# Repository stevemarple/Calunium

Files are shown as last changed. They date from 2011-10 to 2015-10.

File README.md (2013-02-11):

# Calunium

Calunium is an Arduino clone using the ATmega164A, ATmega164PA
ATmega324A, ATmega324PA, ATmega644A, ATmega644PA, ATmega1284 or
ATmega1284P microcontroller. The layout is designed for easy assembly
and maximum compatibility with the Arduino Uno, with additional
functionality being compatible with the Arduino Mega(2560).

## License

Unless indicated otherwise hardware is released under the Creative
Commons Attribution-ShareAlike 3.0 Unported (CC BY-SA 3.0)
http://creativecommons.org/licenses/by-sa/3.0/

Unless indicated otherwise software is released under the GNU Lesser
General Public License, version 2.1.
http://www.gnu.org/licenses/lgpl-2.1.html

## Versions

A brief description of the versions is given below. In each case
peripherals can be omitted form the build if not need.

### Stripboard version

The analogue pin mapping differs slightly for the stripboard
version. For more information see
http://blog.stevemarple.co.uk/2011/08/introducing-calunium-arduino-clone.html

### PCB version 1

Includes a real-time clock and LM61 temperature sensor. Standard
Arduino headers and JTAG, FTDI and auxillary power connectors. USB
connector for power and V-USB interface (not confirmed to work). Can
be operated at 3.3V or 5V depending upon build configuration. Not
jumper selectable. For more information see
http://blog.stevemarple.co.uk/2011/11/calunium-pcb-version.html.

### PCB version 2

Includes real-time clock, micro-SD socket, RFM12B radio module, and
LM61 temperature sensor. Arduino 1.0 headers with IOREF and dedicated
I2C pins. JTAG, FTDI and auxillary power connectors.  USB connector
for power only. Jumper-selectable 3.3V or 5V operation. For more
information see
http://blog.stevemarple.co.uk/2012/12/calunium-version-2.html

### PCB version 2.1

Includes MCP2200 USB-UART converter, real-time clock, micro-SD socket,
RFM12B radio module, and LM61 temperature sensor. Arduino 1.0 headers
with IOREF and dedicated I2C pins. JTAG and auxillary power
connectors. If the MCP2200 is fitted then the FTDI connector cannot be
fitted, but the USB socket is enabled for data. If the MCP2200 is not
fitted the FTDI connector can be, but the USB socket is for power
only. Jumper-selectable 3.3V or 5V operation. For more information see

The headers include
IOREF and dedicated I2C pins. For more information see
http://blog.stevemarple.co.uk/2013/02/calunium-version-21.html and
http://blog.stevemarple.co.uk/2012/12/calunium-version-2.html.

## Bootloader

Xboot and OptiBoot bootloaders are included. To avoid too many items
in boards menu the optiboot versions are commented out.

The xboot source files can be found at
https://github.com/stevemarple/xboot.

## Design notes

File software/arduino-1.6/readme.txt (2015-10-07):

Software to support Calunium in the Arduino IDE. 
Requires Arduino version >= 1.5.

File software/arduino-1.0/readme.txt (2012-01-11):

Software to support Calunium in the Arduino IDE. 
Requires Arduino 1.0.

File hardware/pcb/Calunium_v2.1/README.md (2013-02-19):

# Calunium v2.1 PCB design

Calunium design files for Eagle 6.2.0.

Tested design. Only known error is label for JP9. Order is incorrect and
should read "USB/FTDI" to match jumper position.

## Licence
Creative Commons Attribution-ShareAlike 3.0 Unported (CC BY-SA 3.0)
http://creativecommons.org/licenses/by-sa/3.0/

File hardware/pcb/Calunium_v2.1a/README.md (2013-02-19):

# Calunium v2.1a PCB design

Calunium design files for Eagle 6.2.0.

Identical to Calunium v2.1 but corrects for silkscreen error on JP9.

## Licence
Creative Commons Attribution-ShareAlike 3.0 Unported (CC BY-SA 3.0)
http://creativecommons.org/licenses/by-sa/3.0/

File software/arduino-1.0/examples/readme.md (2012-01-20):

# Software examples

These software examples should work unchanged on a Calunium, for other
ATmega*4 devices you may need to use a different pin number; make sure
you use the same MCU pin as here. Arduino users will probably need to
make some changes; see the comments in the code.

## RTCInterrupts

An example sketch which uses Calunium's on-board real-time clock to
create interrupts which are processed by the INT2 interrupt service
routine.

## RTCPinChangeInterrupts

An example sketch which uses Calunium's on-board real-time clock to
create pin-change interrupts.

## RTCTimerCounter

An example sketch which uses Calunium's on-board real-time clock to
drive the counter stage of timer/counter2. When the counter reaches a
predetermined value (but not overflow) an interrupt is generated.

## RTCSquareWaveOff

An example sketch to turn off the square wave output of the real-time
clock.

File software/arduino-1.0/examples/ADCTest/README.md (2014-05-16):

# ADCTest.ino
 
Example sketch to demonstrate using the analogue to digital
converters, and how to change the analogue reference.

The output of all ADCs are continously printed to the serial port,
with a 1s delay between each set of readings. The analogue
reference can be changed during operation by sending one of the
following characters:
    1: Set analog reference to INTERNAL1V1");
    2: Set analog reference to INTERNAL2V56");
    d: Set analog reference to DEFAULT (Vcc)");
    e: Set analog reference to EXTERNAL");
Sending h (or ?) prints help information about the characters which
are accepted.

Author: Steve Marple
License: GNU General Public License version 2

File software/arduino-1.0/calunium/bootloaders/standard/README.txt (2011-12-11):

Bootloader files from Ryan M Sutton:http://ryanmsutton.com/2011/06/arduino-bootloader-for-atmega-1284p/
Makefile by Steve Marple

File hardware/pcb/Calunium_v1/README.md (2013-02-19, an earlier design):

# Calunium v1

Proven design. Requires v1.0 Arduino IDE to support the reversed
analogue pin mapping. 

## Known errors

The only known errors are very minor issues with the silkscreen printing:
* "JP5" should be "JP5 (D7)" to indicate it affects D7.
* The value for IC1 should be MCP1702, not LM1702.

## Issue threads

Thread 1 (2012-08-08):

SoftwareSerial does not compile with Calunium's pins_arduino.h

kfuglsang, 2012-08-08:
When including SoftwareSerial into the Arduino 1.0.1 IDE targeting Calunium 1284P the code wont compile due to compilation errors in SoftwareSerial.cpp.

arduino-1.0.1\libraries\SoftwareSerial\SoftwareSerial.cpp: In member function 'void SoftwareSerial::begin(long int)':
arduino-1.0.1\libraries\SoftwareSerial\SoftwareSerial.cpp:398: error: operands to ?: have different types 'int' and 'uint8_t*'
arduino-1.0.1\libraries\SoftwareSerial\SoftwareSerial.cpp:399: error: expected primary-expression before ']' token
arduino-1.0.1\libraries\SoftwareSerial\SoftwareSerial.cpp:399: error: operands to ?: have different types 'int' and 'uint8_t*'
arduino-1.0.1\libraries\SoftwareSerial\SoftwareSerial.cpp: In member function 'void SoftwareSerial::end()':
arduino-1.0.1\libraries\SoftwareSerial\SoftwareSerial.cpp:414: error: expected primary-expression before ']' token
arduino-1.0.1\libraries\SoftwareSerial\SoftwareSerial.cpp:415: error: expected primary-expression before ']' token
arduino-1.0.1\libraries\SoftwareSerial\SoftwareSerial.cpp:415: error: operands to ?: have different types 'int' and 'uint8_t*'

I found that the problem occurs due to these lines in pins_arduino.h:
#define digitalPinToPCICR(p)    ifpin(p,&PCICR,(uint8_t *)0)
#define digitalPinToPCICRbit(p) ifpin(p,digital_pin_to_pcint[p] >> 3,(uint8_t *)0)
#define digitalPinToPCMSK(p)    ifpin(p,__pcmsk[digital_pin_to_pcint[]],(uint8_t *)0)
#define digitalPinToPCMSKbit(p) ifpin(p,digital_pin_to_pcint[p] & 0x7,(uint8_t *)0)

Changing them to this makes it compilable:
#define digitalPinToPCICR(p)    ifpin(p,&PCICR,(uint8_t *)0)
#define digitalPinToPCICRbit(p) ifpin(p, digital_pin_to_pcint[p] >> 3, 0)
#define digitalPinToPCMSK(p)    ifpin(p,(uint16_t *)__pcmsk[digital_pin_to_pcint[p]],(uint16_t *)0)
#define digitalPinToPCMSKbit(p) ifpin(p, digital_pin_to_pcint[p] & 0x7, 0)

deladriere, 2015-05-28:
Hi Steve
I can compile but cannot use SoftwareSerial
It works on Arduino Uno but the same code (SoftwareSerialExample) doesn't work on Calunium
Did you succeed using it ?
Thx

stevemarple, 2015-05-28:
@deladriere With two hardware UARTs I've never had the need to use SoftwareSerial.
What pins are you trying to use? If those pins are configured for other functionality that will prevent their use as normal I/O.
Are you sure you have the correct hardware pins?

deladriere, 2015-05-29:
I am trying this code
TX pins are OK but not RX did works (I've tried many pins)
```
/*
  Software serial multple serial test

 Receives from the hardware serial, sends to software serial.
 Receives from software serial, sends to hardware serial.

 The circuit:
 * RX is digital pin 10 (connect to TX of other device)
 * TX is digital pin 11 (connect to RX of other device)

 Note:
 Not all pins on the Mega and Mega 2560 support change interrupts,
 so only the following can be used for RX:
 10, 11, 12, 13, 50, 51, 52, 53, 62, 63, 64, 65, 66, 67, 68, 69

 Not all pins on the Leonardo support change interrupts,
 so only the following can be used for RX:
 8, 9, 10, 11, 14 (MISO), 15 (SCK), 16 (MOSI).

 created back in the mists of time
 modified 25 May 2012
 by Tom Igoe
 based on Mikal Hart's example

 This example code is in the public domain.

 */
#include <SoftwareSerial.h>

SoftwareSerial mySerial(10, 11); // RX, TX

void setup()
{
  // Open serial communications and wait for port to open:
  Serial.begin(57600);
  while (!Serial) {
    ; // wait for serial port to connect. Needed for Leonardo only
  }

  Serial.println("Goodnight moon!");

  // set the data rate for the SoftwareSerial port
  mySerial.begin(4800);
  mySerial.println("Hello, world?");
}

void loop() // run over and over
{
  if (mySerial.available())
    Serial.write(mySerial.read());
  if (Serial.available())
    mySerial.write(Serial.read());
}
```

stevemarple, 2015-05-31:
Digital pin 10 is the slave select (/SS) for the SPI port. It's normally recommended that it is kept as an output; you're not using SPI so I'm not sure if that still applies. Could you try another pin?

deladriere, 2016-01-14:
Hi Steve just installed the lasted version and still cannot work with the SoftwareSerial
SoftwareSerial mySerial(8, 15); // RX, TX
If I use the Maniacbug board definition (from [https://github.com/JChristensen/mighty-1284p](https://github.com/JChristensen/mighty-1284p)) it works fine on the same hardware & pins (with the corrected pin number of course)
Did you ever had success using SoftwareSerial?

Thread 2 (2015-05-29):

Arduino 1.6.4 support

deladriere, 2015-05-29:
Hi Steve
any plan to add your board here : https://github.com/arduino/Arduino/wiki/Unofficial-list-of-3rd-party-boards-support-urls ?

ps why does the Mighty has no own core and the Calunium needs one ?

Can we just have one install for all 1284P and have all variants in one place like here : https://github.com/JChristensen/mighty-1284p

thx !

stevemarple, 2015-05-31:
I'll look into making a pull request to add the details of Calunium.

One reason calunium has its own core is because it needs an `analogInputToDigitalPin()` function to map the analogue inputs.

deladriere, 2015-06-15:
This is marked as closed
Where can I find the board setting for the Arduino 1.6.4 ?
Thx

majenkotech, 2015-06-23:
> One reason calunium has its own core is because it needs an analogInputToDigitalPin() function to map the analogue inputs.

Why does that make calunium special?  Other boards (including standard Arduino boards) have that "function" (actually a macro, not a function), so what is so special about the calunium core?

stevemarple, 2015-06-23:
The issue is probably better described as needing ``digitalPinToAnalogPin()``, which can be seen in commit aa95f67f9c6b991a2ca9a01da585dacab9be3939. wiring_analog.c only used the ``digitalPinToAnalogPin()`` macro for selected architectures, ATmega644(P)/ATmega1284(P) was not one of them.

I haven't updated to the latest Arduino code for a while but looking at the Github repository it seems that issue should now be solved, see https://github.com/arduino/Arduino/commit/938351bcae71b2ede100e5da29bd8d9e313264b5

I'll try to update to a newer Arduino software version and see if needing a separate core can be avoided but it isn't a priority for me right now.

deladriere, 2016-01-14:
Could you also add the optiboot 16 MHz version to 1.6?
thx

Closed 2015-05-31.

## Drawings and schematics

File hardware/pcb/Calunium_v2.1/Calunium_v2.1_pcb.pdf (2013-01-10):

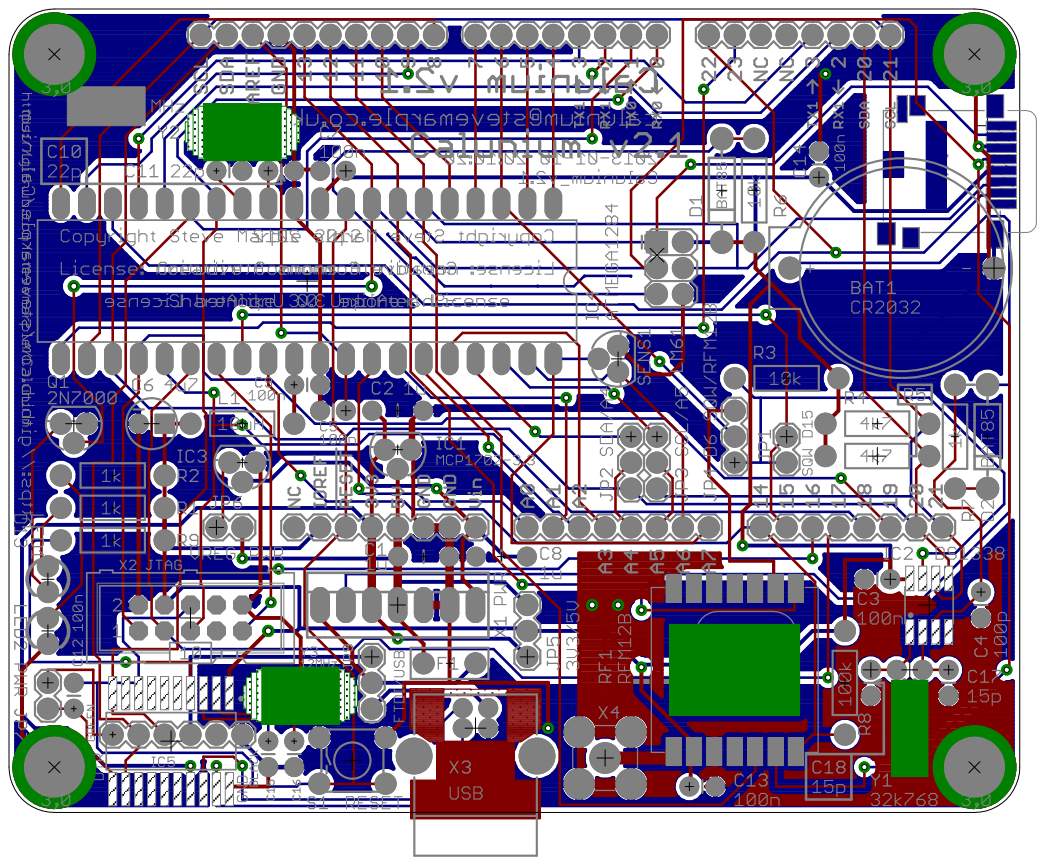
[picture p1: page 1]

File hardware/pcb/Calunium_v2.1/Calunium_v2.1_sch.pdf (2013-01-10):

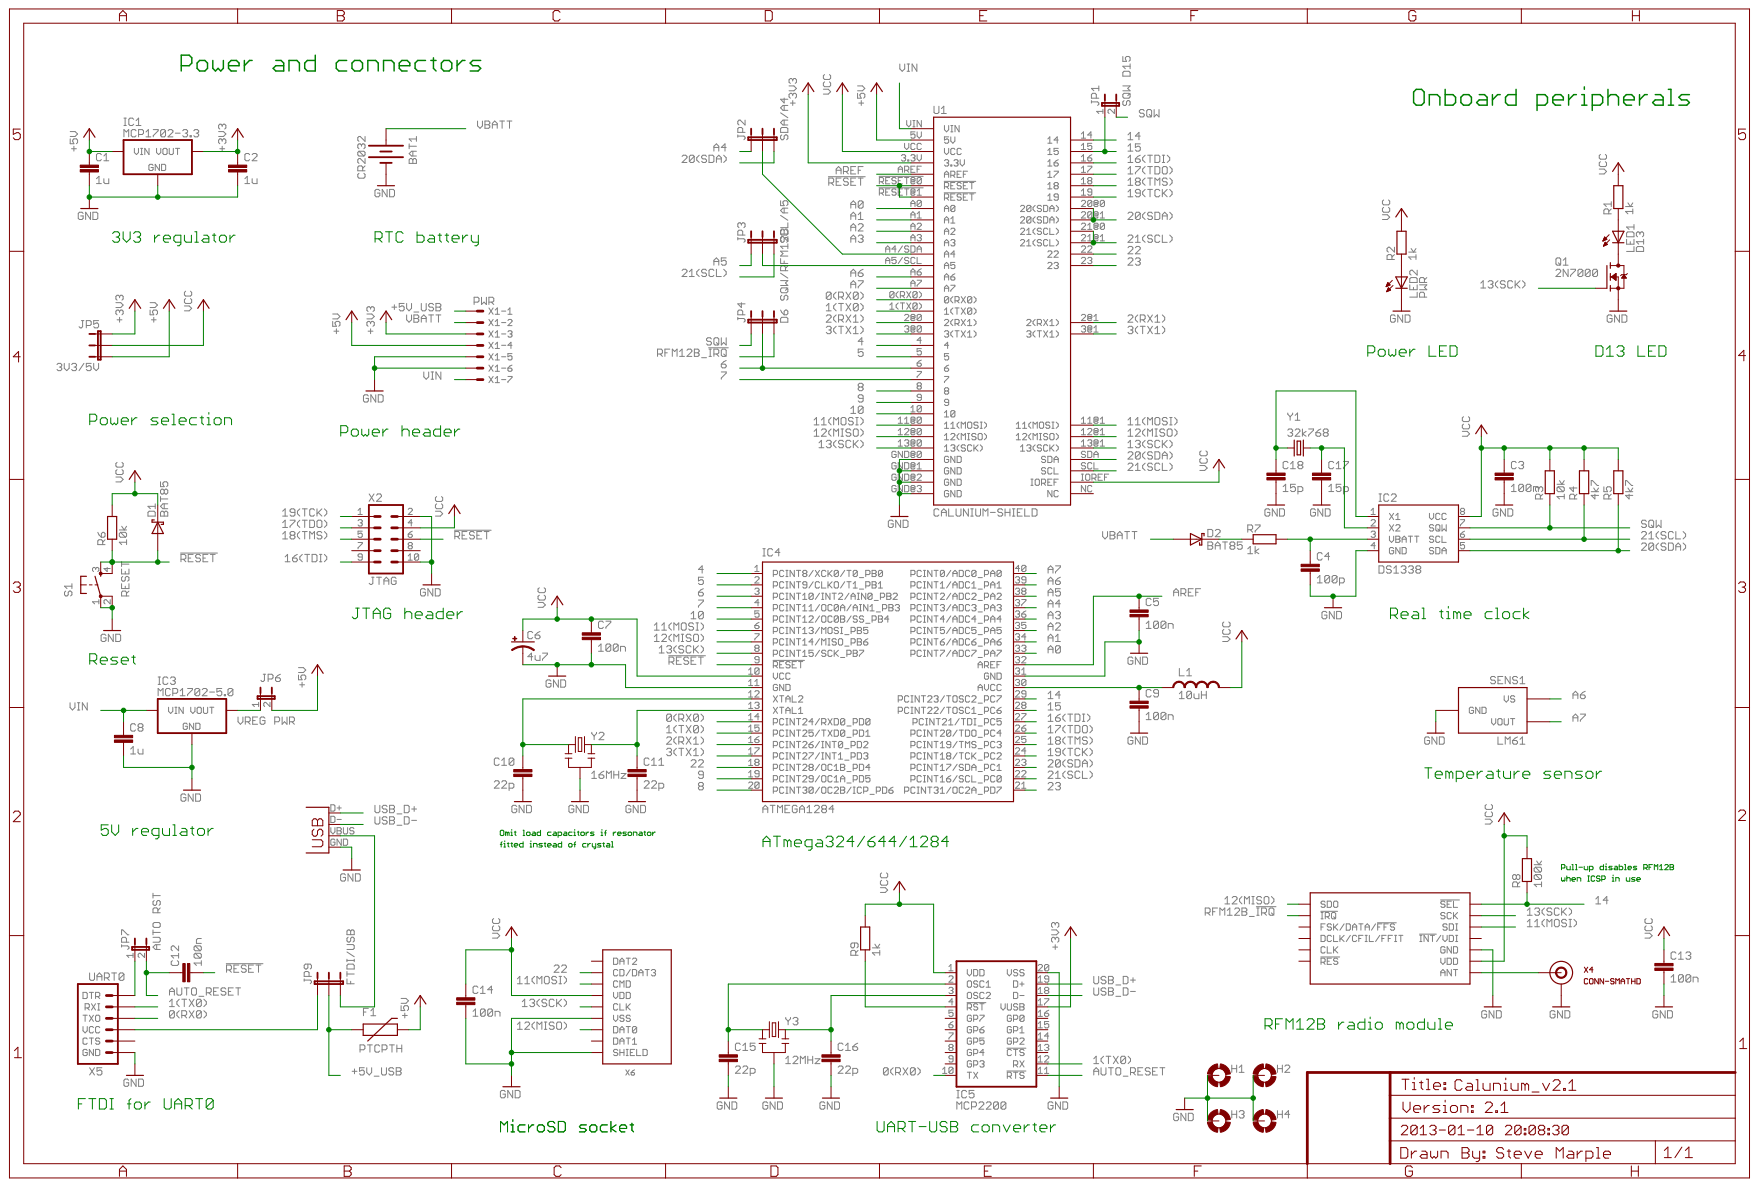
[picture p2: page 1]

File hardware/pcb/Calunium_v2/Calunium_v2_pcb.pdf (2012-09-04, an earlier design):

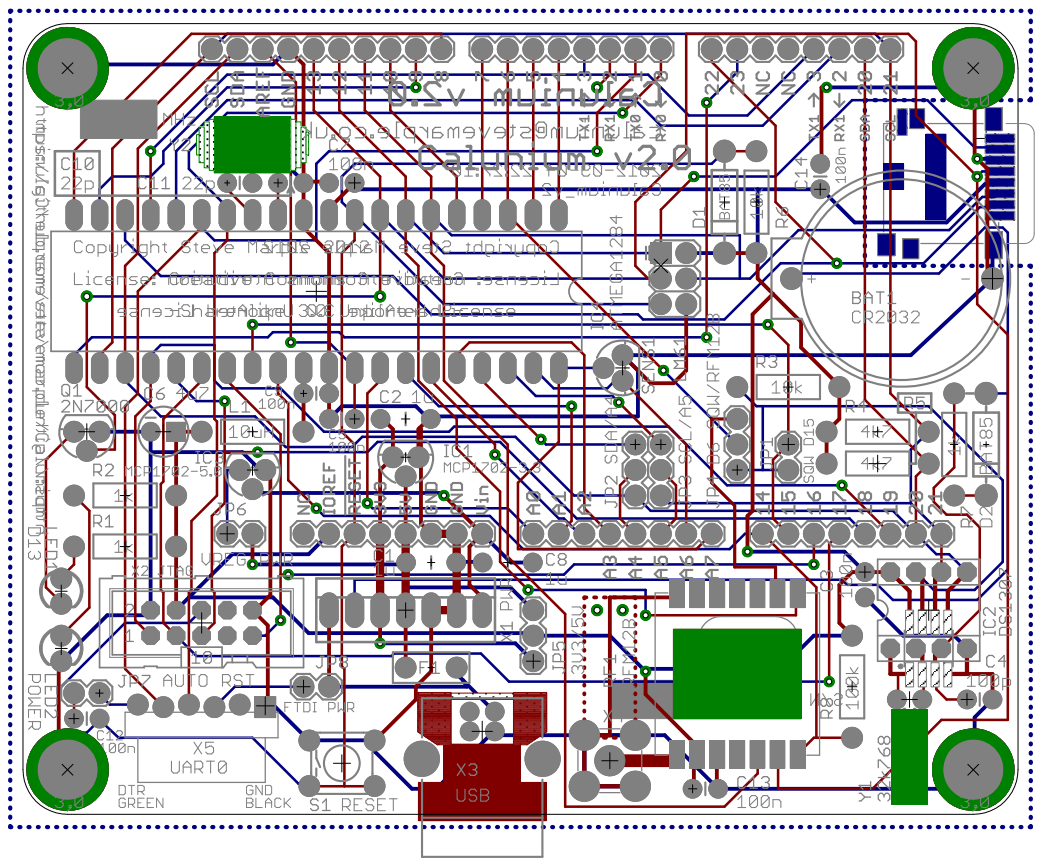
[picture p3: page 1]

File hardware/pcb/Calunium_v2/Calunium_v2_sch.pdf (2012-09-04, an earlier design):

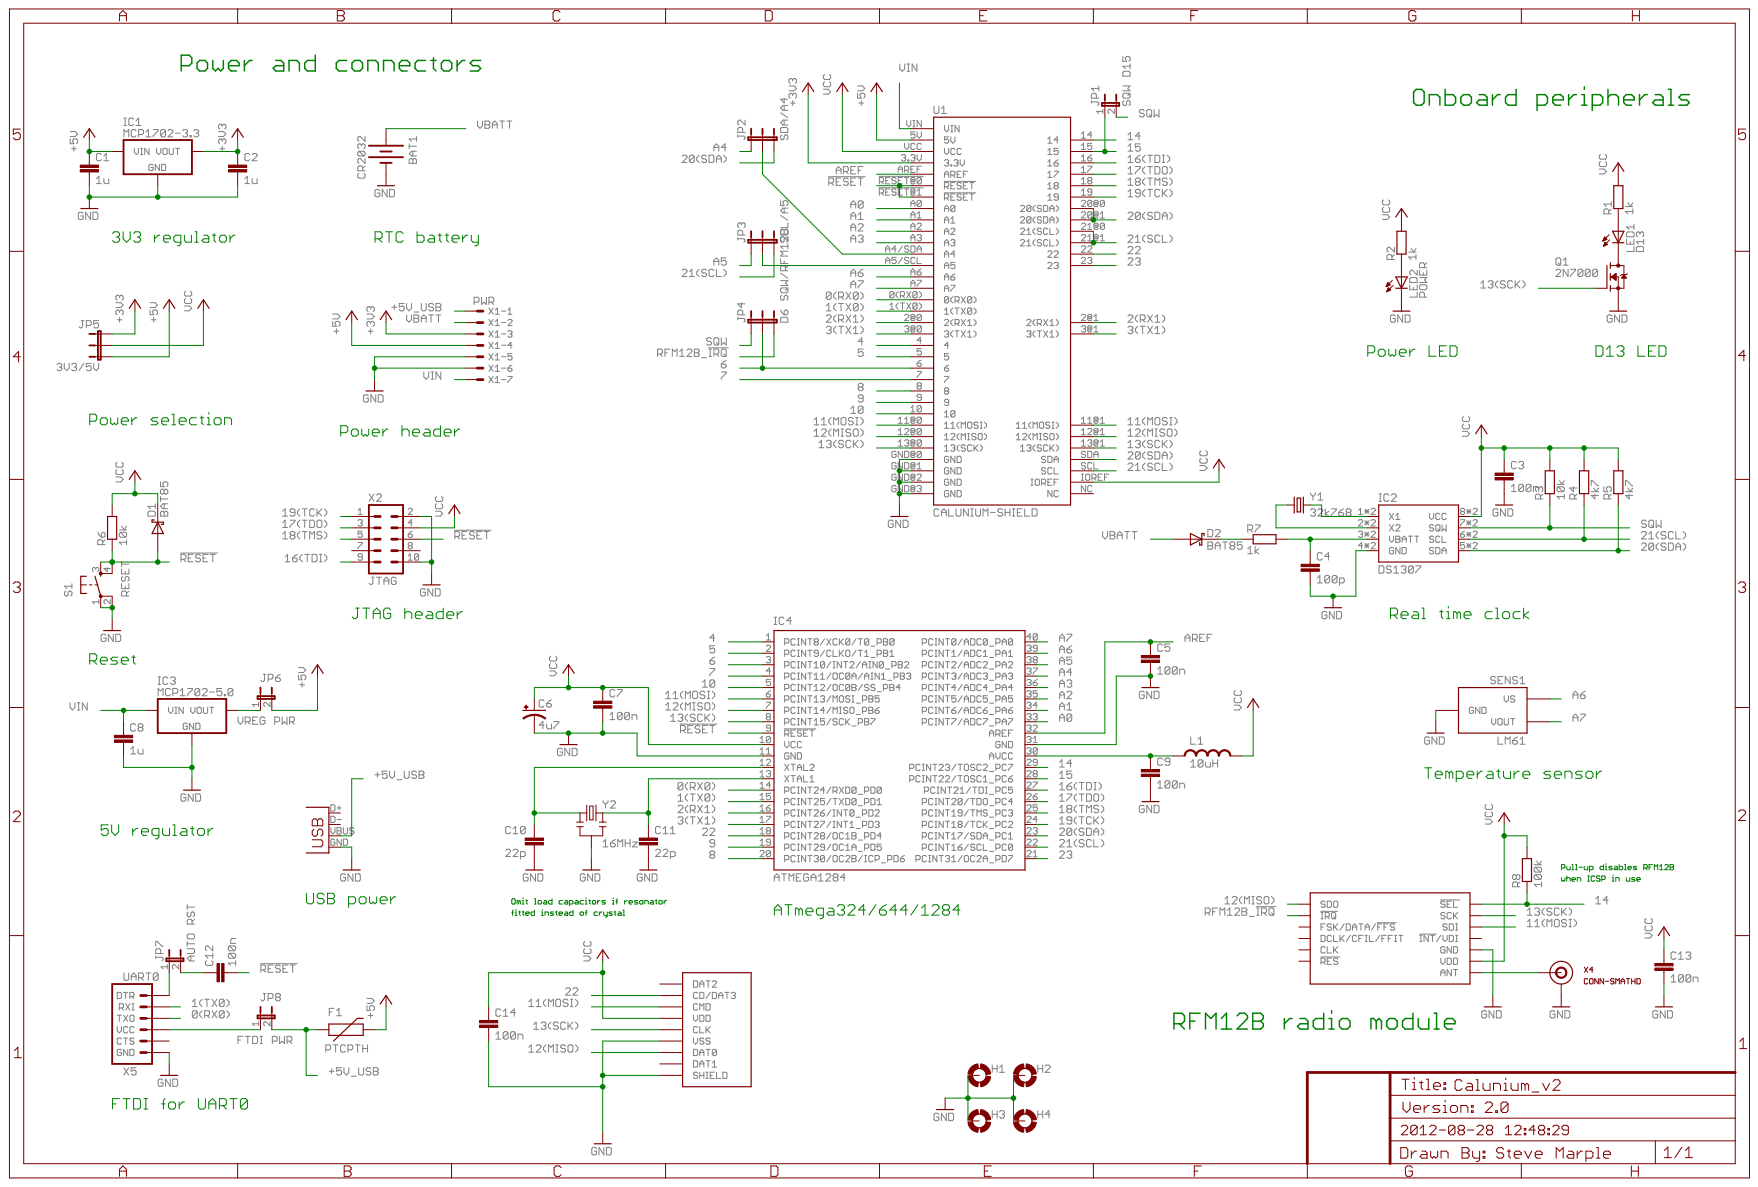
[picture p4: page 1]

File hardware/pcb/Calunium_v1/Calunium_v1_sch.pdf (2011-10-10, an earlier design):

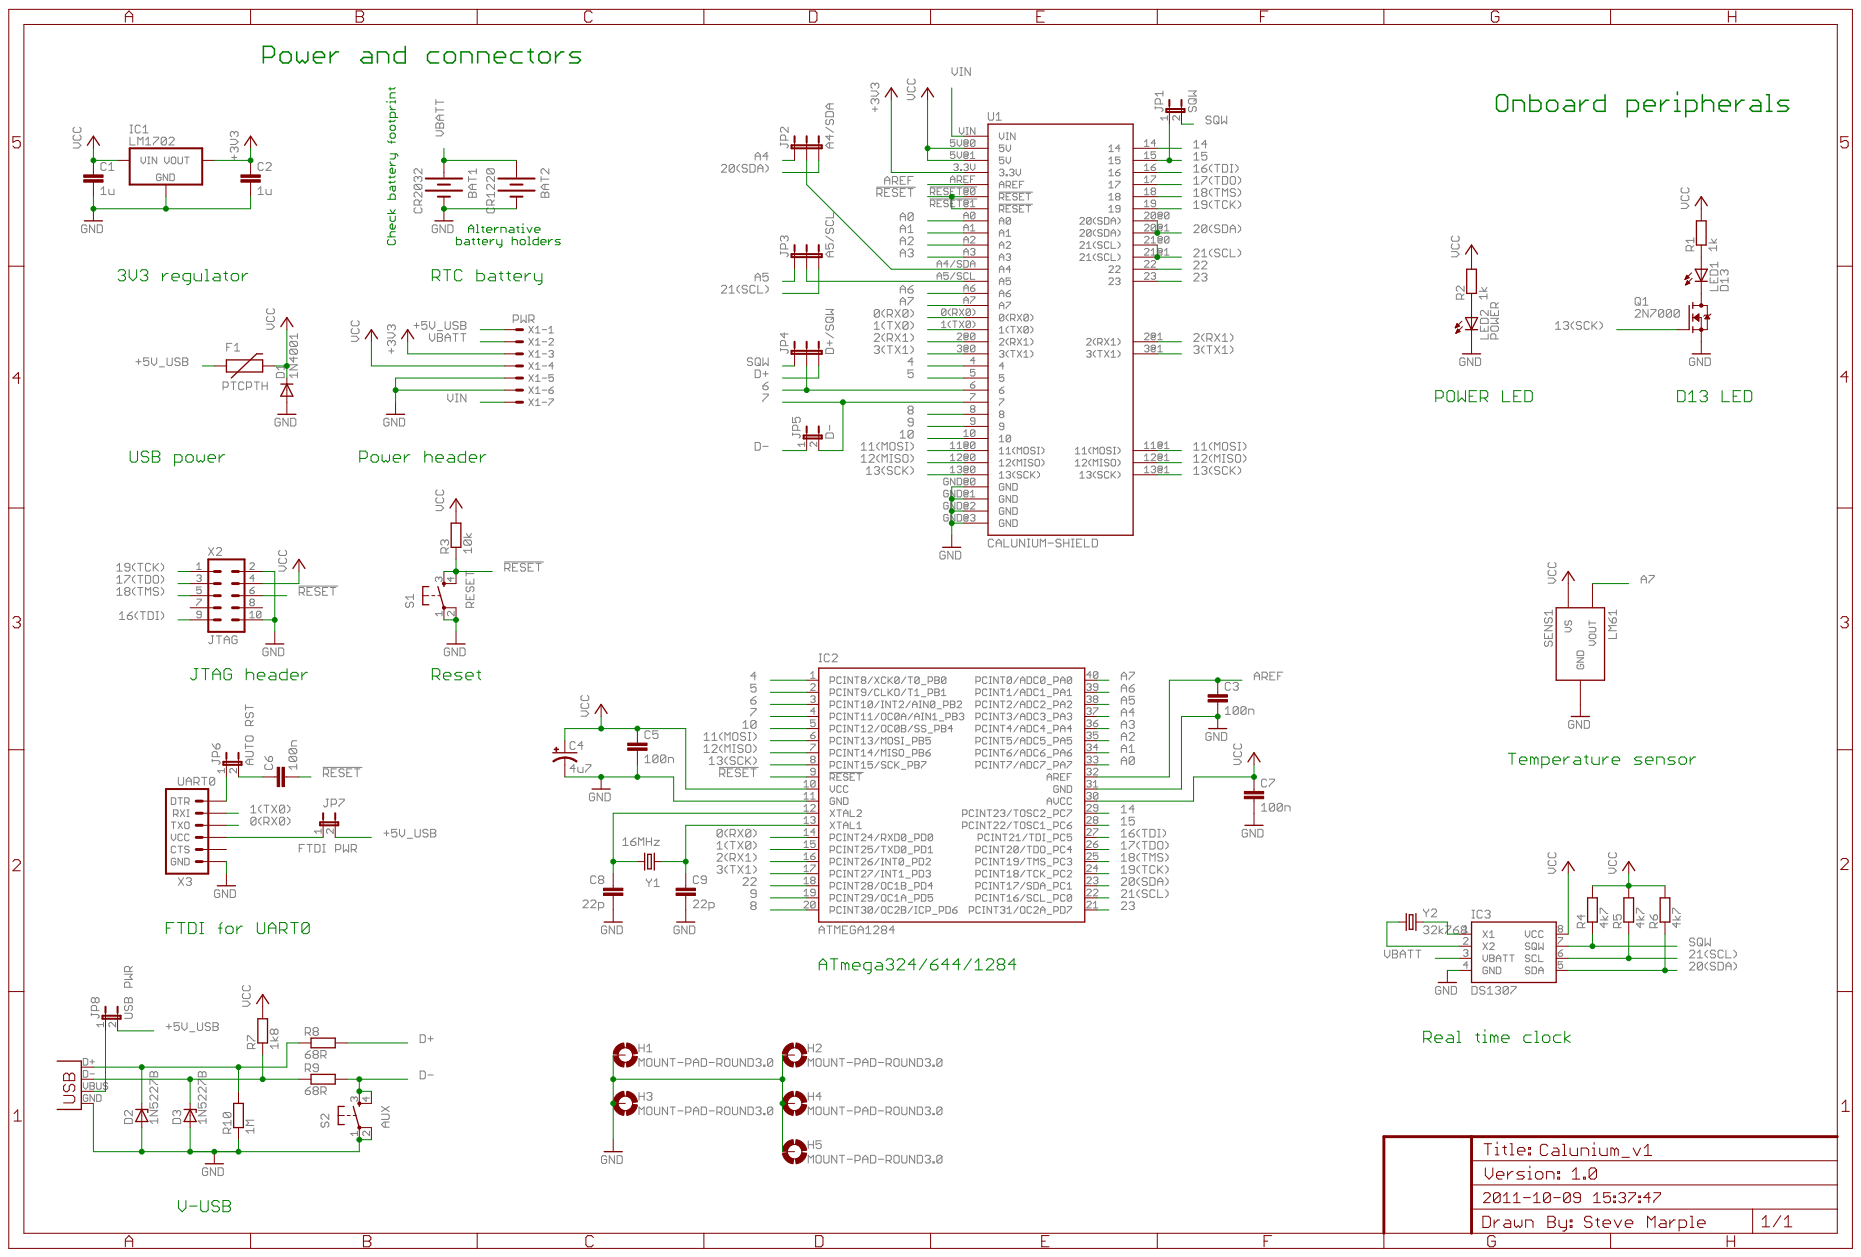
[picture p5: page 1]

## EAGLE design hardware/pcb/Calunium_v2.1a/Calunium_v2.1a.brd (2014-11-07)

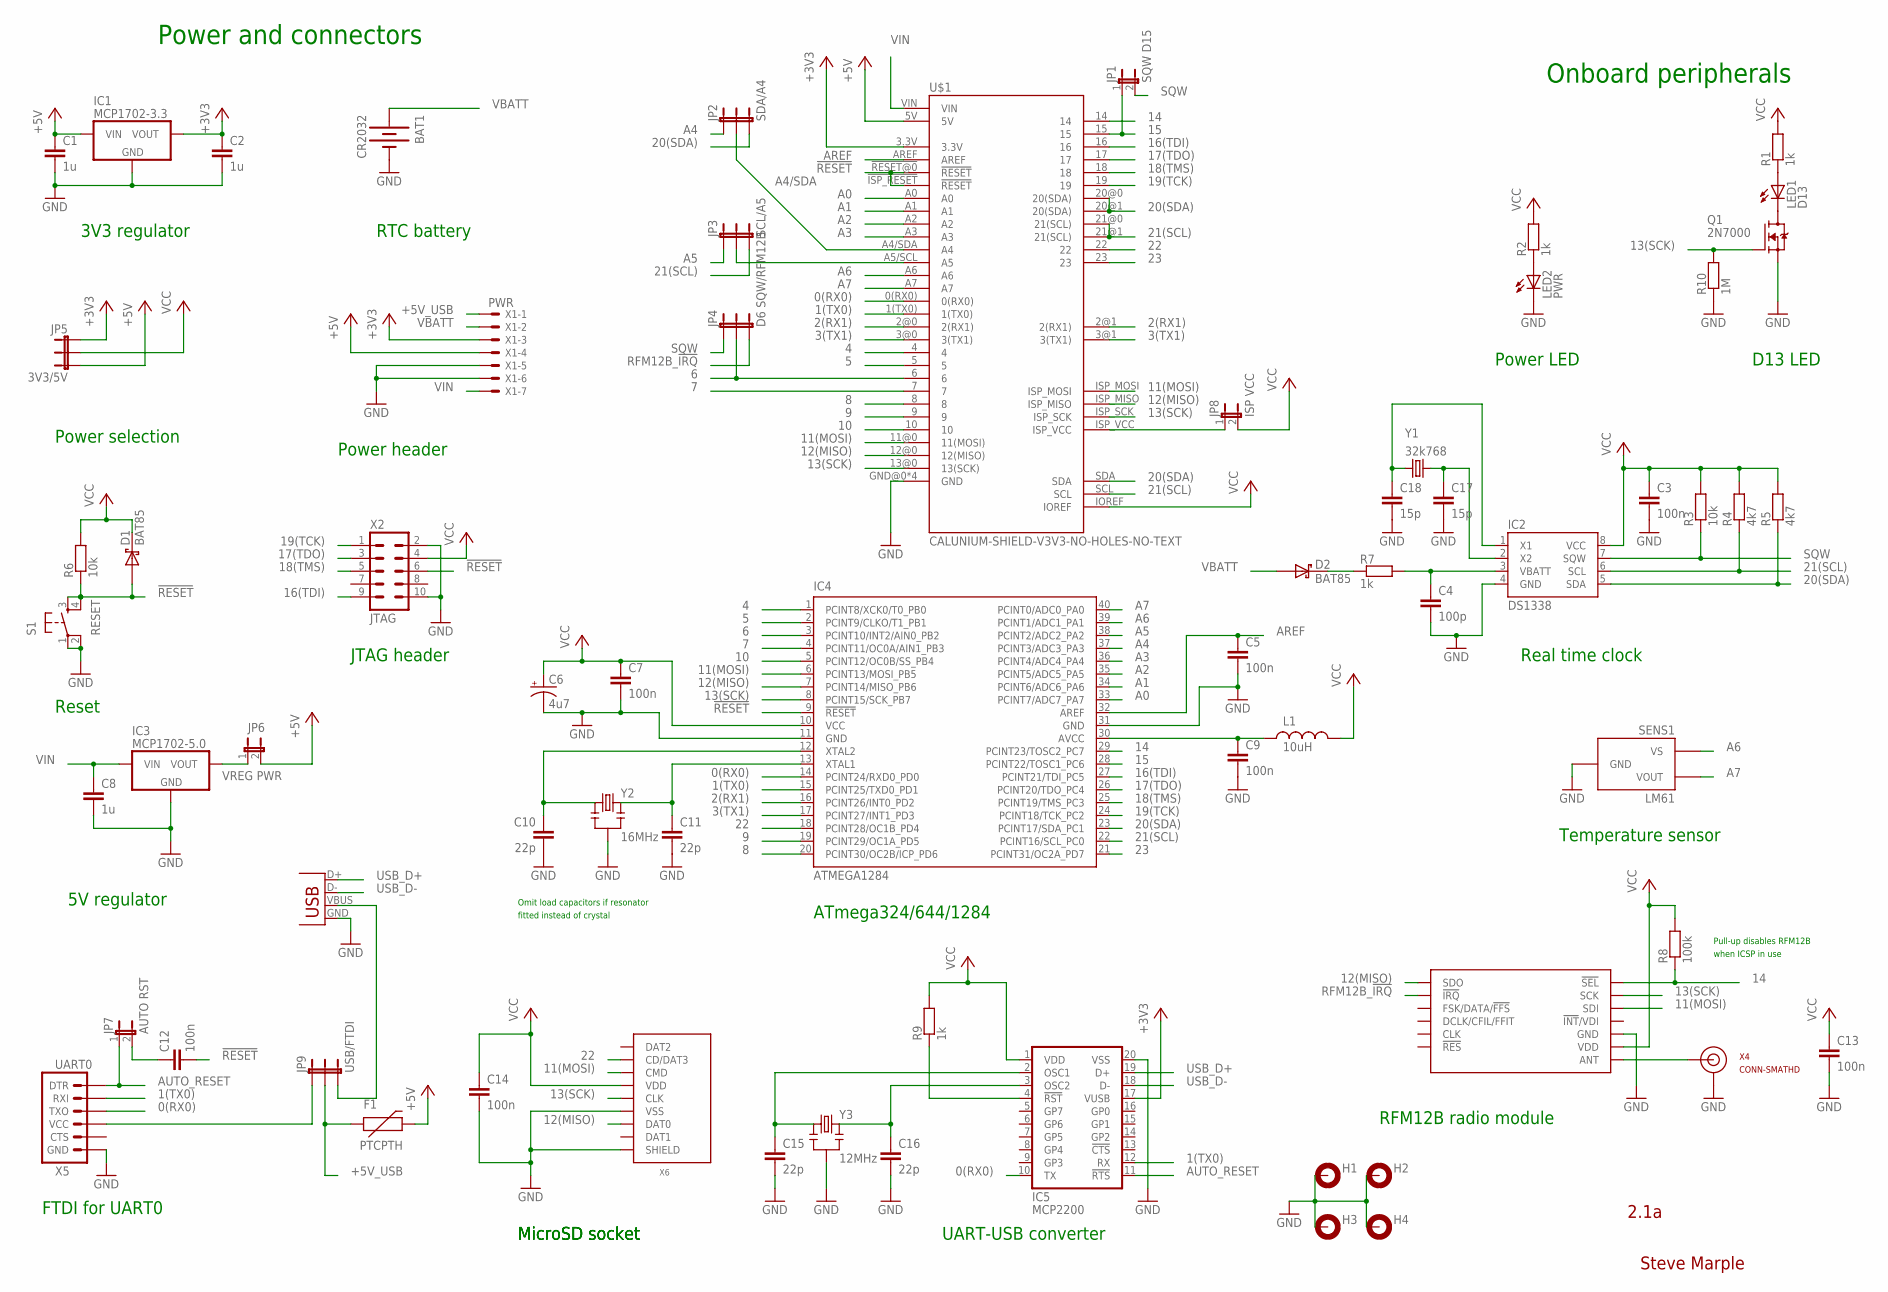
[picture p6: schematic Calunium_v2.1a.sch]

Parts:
BAT1: CR2032; BATTCOM_20MM_PTH
C1, C2, C8: 1u; CAP-PTH-5MM
C3, C5, C7, C9, C12, C13, C14: 100n; CAP-PTH-SMALL
C4: 100p; CAP-PTH-SMALL
C6: 4u7; CPOL-RADIAL-10UF-25V
C10, C11, C15, C16: 22p; CAP-PTH-SMALL
C17, C18: 15p; CAP-PTH-SMALL
D1, D2: BAT85; DIODE-TH-0.4
F1: PTCPTH; PTC
H1, H2, H3, H4: MOUNT-PAD-ROUND3.0; 3,0-PAD
IC1: MCP1702-3.3; TO-92
IC2: DS1338; SO08
IC3: MCP1702-5.0; TO-92
IC4: ATMEGA1284; DIL40
IC5: MCP2200; SO20
JP1: SQW D15; 1X02
JP2: SDA/A4; 1X03
JP3: SCL/A5; 1X03
JP4: D6 SQW/RFM12B; 1X03
JP5: 3V3/5V; 1X03
JP6: VREG PWR; 1X02
JP7: AUTO RST; 1X02
JP8: ISP VCC; 1X02
JP9: USB/FTDI; 1X03
L1: 10uH; RES-AXIAL-0.4
LED1: D13; LED3MM
LED2: PWR; LED3MM
Q1: 2N7000; TO-92
R1, R2, R7, R9: 1k; RES-AXIAL-0.4
R3, R6: 10k; RES-AXIAL-0.4
R4, R5: 4k7; RES-AXIAL-0.4
R8: 100k; RES-AXIAL-0.4
R10: 1M; RES-AXIAL-0.4
RF1: RFM12B
S1: RESET; TACTILE-PTH
SENS1: LM61; TO-92
U$1: CALUNIUM-SHIELD-V3V3-NO-HOLES-NO-TEXT; CALUNIUM-SHIELD-NO-OUTLINE-NO-HOLES-NO-TEXT-V3
X1: PWR; 22-23-2071
X2: JTAG; CON-HARTING-ML10
X3: USB; USB-B-PTH
X4: CONN-SMATHD; SMA-THD
X5: UART0; 1X06
X6: MICRO-SD-SOCKETHIROSE-DM3D; MICRO-SD-SOCKET-HIROSE-DM3D
Y1: 32k768; TC38H
Y2: 16MHz; HC49U-V-RESONATOR
Y3: 12MHz; HC49U-V-RESONATOR

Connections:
0(RX0): IC4.14 (PCINT24/RXD0_PD0), IC5.10 (TX), U$1.0(RX0), X5.3 (TXO)
1(TX0): IC4.15 (PCINT25/TXD0_PD1), IC5.12 (RX), U$1.1(TX0), X5.2 (RXI)
2(RX1): IC4.16 (PCINT26/INT0_PD2), U$1.2@0 (2(RX1)), U$1.2@1 (2(RX1))
3(TX1): IC4.17 (PCINT27/INT1_PD3), U$1.3@0 (3(TX1)), U$1.3@1 (3(TX1))
4: IC4.1 (PCINT8/XCK0/T0_PB0), U$1.4
5: IC4.2 (PCINT9/CLKO/T1_PB1), U$1.5
6: IC4.3 (PCINT10/INT2/AIN0_PB2), JP4.2, U$1.6
7: IC4.4 (PCINT11/OC0A/AIN1_PB3), U$1.7
8: IC4.20 (PCINT30/OC2B/ICP_PD6), U$1.8
9: IC4.19 (PCINT29/OC1A_PD5), U$1.9
10: IC4.5 (PCINT12/OC0B/SS_PB4), U$1.10
11(MOSI): IC4.6 (PCINT13/MOSI_PB5), RF1.SDI, U$1.11@0 (11(MOSI)), U$1.ISP_MOSI, X6.CMD
12(MISO): IC4.7 (PCINT14/MISO_PB6), RF1.SDO, U$1.12@0 (12(MISO)), U$1.ISP_MISO, X6.DAT0
13(SCK): IC4.8 (PCINT15/SCK_PB7), Q1.2 (G), R10.P$2 (2), RF1.SCK, U$1.13@0 (13(SCK)), U$1.ISP_SCK, X6.CLK
14: IC4.29 (PCINT23/TOSC2_PC7), R8.P$1 (1), RF1.!SEL, U$1.14
15: IC4.28 (PCINT22/TOSC1_PC6), JP1.1, U$1.15
16(TDI): IC4.27 (PCINT21/TDI_PC5), U$1.16, X2.9 (TDI)
17(TDO): IC4.26 (PCINT20/TDO_PC4), U$1.17, X2.3 (TDO)
18(TMS): IC4.25 (PCINT19/TMS_PC3), U$1.18, X2.5 (TMS)
19(TCK): IC4.24 (PCINT18/TCK_PC2), U$1.19, X2.1 (TCK)
20(SDA): IC2.5 (SDA), IC4.23 (PCINT17/SDA_PC1), JP2.3, R5.P$1 (1), U$1.20@0 (20(SDA)), U$1.20@1 (20(SDA)), U$1.SDA
21(SCL): IC2.6 (SCL), IC4.22 (PCINT16/SCL_PC0), JP3.3, R4.P$1 (1), U$1.21@0 (21(SCL)), U$1.21@1 (21(SCL)), U$1.SCL
22: IC4.18 (PCINT28/OC1B_PD4), U$1.22, X6.CD/DAT3
23: IC4.21 (PCINT31/OC2A_PD7), U$1.23
!RESET: C12.2, D1.A, IC4.9 (!RESET), R6.P$1 (1), S1.3, S1.4, U$1.!ISP_RESET (!RESET), U$1.!RESET@0 (!RESET), X2.6 (!SRST)
+3V3: C2.1, IC1.3 (VOUT), IC5.17 (VUSB), JP5.1, U$1.3.3V, X1.3
+5V: C1.1, F1.P$2 (2), IC1.2 (VIN), JP5.3, JP6.2, U$1.5V, X1.4
+5V_USB: F1.P$1 (1), JP9.2, X1.1
A0: IC4.33 (PCINT7/ADC7_PA7), U$1.A0
A1: IC4.34 (PCINT6/ADC6_PA6), U$1.A1
A2: IC4.35 (PCINT5/ADC5_PA5), U$1.A2
A3: IC4.36 (PCINT4/ADC4_PA4), U$1.A3
A4: IC4.37 (PCINT3/ADC3_PA3), JP2.1
A4/SDA: JP2.2, U$1.A4/SDA (A4)
A5: IC4.38 (PCINT2/ADC2_PA2), JP3.1
A5/SCL: JP3.2, U$1.A5/SCL (A5)
A6: IC4.39 (PCINT1/ADC1_PA1), SENS1.1 (VS), U$1.A6
A7: IC4.40 (PCINT0/ADC0_PA0), SENS1.2 (VOUT), U$1.A7
AREF: C5.1, IC4.32 (AREF), U$1.AREF
AUTO_RESET: IC5.11 (!RTS), JP7.1, X5.1 (DTR)
AVCC: C9.1, IC4.30 (AVCC), L1.P$1 (1)
GND: BAT1.2 (-), C1.2, C2.2, C3.2, C4.2, C5.2, C6.2 (-), C7.2, C8.2, C9.2, C10.2, C11.2, C13.2, C14.2, C15.2, C16.2, C17.2, C18.2, H1.B3,0, H2.B3,0, H3.B3,0, H4.B3,0, IC1.1 (GND), IC2.4 (GND), IC3.1 (GND), IC4.11 (GND), IC4.31 (GND), IC5.20 (VSS), LED2.K (C), Q1.1 (S), R10.P$1 (1), RF1.GND@0 (GND), RF1.GND@1 (GND), S1.1, S1.2, SENS1.3 (GND), U$1.GND@0 (GND), U$1.GND@1 (GND), U$1.GND@2 (GND), U$1.GND@3 (GND), X1.5, X1.6, X2.2 (GND), X2.10 (GND), X3.GND, X4.GND@0 (GND), X4.GND@1 (GND), X4.GND@2 (GND), X4.GND@3 (GND), X5.6 (GND), X6.GND (VSS), X6.SHIELD@0 (SHIELD), Y2.GND (2), Y3.GND (2)
unnamed: C11.1, IC4.13 (XTAL1), Y2.2 (3)
unnamed: C10.1, IC4.12 (XTAL2), Y2.1
unnamed: LED1.A, R1.P$1 (1)
unnamed: LED1.K (C), Q1.3 (D)
unnamed: C18.1, IC2.1 (X1), Y1.2
unnamed: JP8.1, U$1.ISP_VCC
unnamed: C16.1, IC5.3 (OSC2), Y3.2 (3)
unnamed: LED2.A, R2.P$1 (1)
unnamed: D2.C, R7.P$1 (1)
unnamed: JP9.1, X5.4 (VCC)
unnamed: C4.1, IC2.3 (VBATT), R7.P$2 (2)
unnamed: C17.1, IC2.2 (X2), Y1.1
unnamed: IC3.3 (VOUT), JP6.1
unnamed: C12.1, JP7.2
unnamed: JP9.3, X3.VBUS
unnamed: RF1.ANT, X4.SIG (SIGNAL)
unnamed: C15.1, IC5.2 (OSC1), Y3.1
unnamed: IC5.4 (!RST), R9.P$1 (1)
RFM12B_!IRQ: JP4.3, RF1.!IRQ
SQW: IC2.7 (SQW), JP1.2, JP4.1, R3.P$1 (1)
USB_D+: IC5.19 (D+), X3.D+
USB_D-: IC5.18 (D-), X3.D-
VBATT: BAT1.1 (+), D2.A, X1.2
VCC: C3.1, C6.1 (+), C7.1, C13.1, C14.1, D1.C, IC2.8 (VCC), IC4.10 (VCC), IC5.1 (VDD), JP5.2, JP8.2, L1.P$2 (2), R1.P$2 (2), R2.P$2 (2), R3.P$2 (2), R4.P$2 (2), R5.P$2 (2), R6.P$2 (2), R8.P$2 (2), R9.P$2 (2), RF1.VDD, U$1.IOREF, X2.4 (VTREF), X6.VDD
VIN: C8.1, IC3.2 (VIN), U$1.VIN, X1.7

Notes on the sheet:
Power and connectors
Onboard peripherals
Real time clock
Temperature sensor
ATmega324/644/1284
FTDI for UART0
JTAG header
D13 LED
Reset
Power selection
Power header
3V3 regulator
RTC battery
Power LED
Steve Marple
2.1a
RFM12B radio module
5V regulator
Pull-up disables RFM12B
when ICSP in use
Omit load capacitors if resonator
fitted instead of crystal
MicroSD socket
UART-USB converter

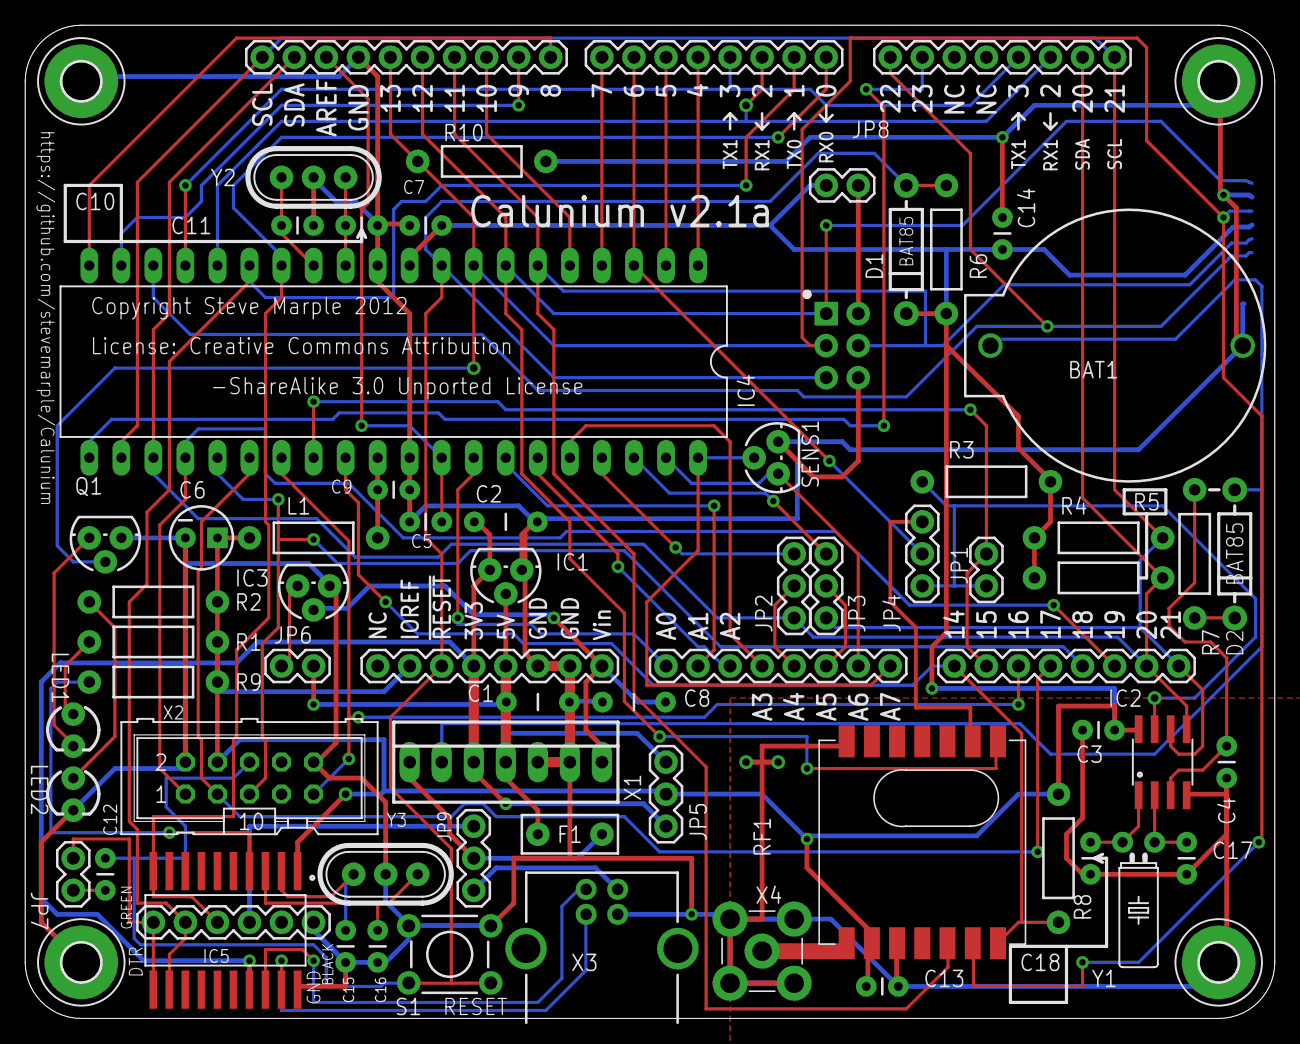
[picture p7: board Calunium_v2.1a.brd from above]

Board: 2 copper layers, 99.1 x 78.7 mm, 67 parts (1 on the bottom side), 67 nets.

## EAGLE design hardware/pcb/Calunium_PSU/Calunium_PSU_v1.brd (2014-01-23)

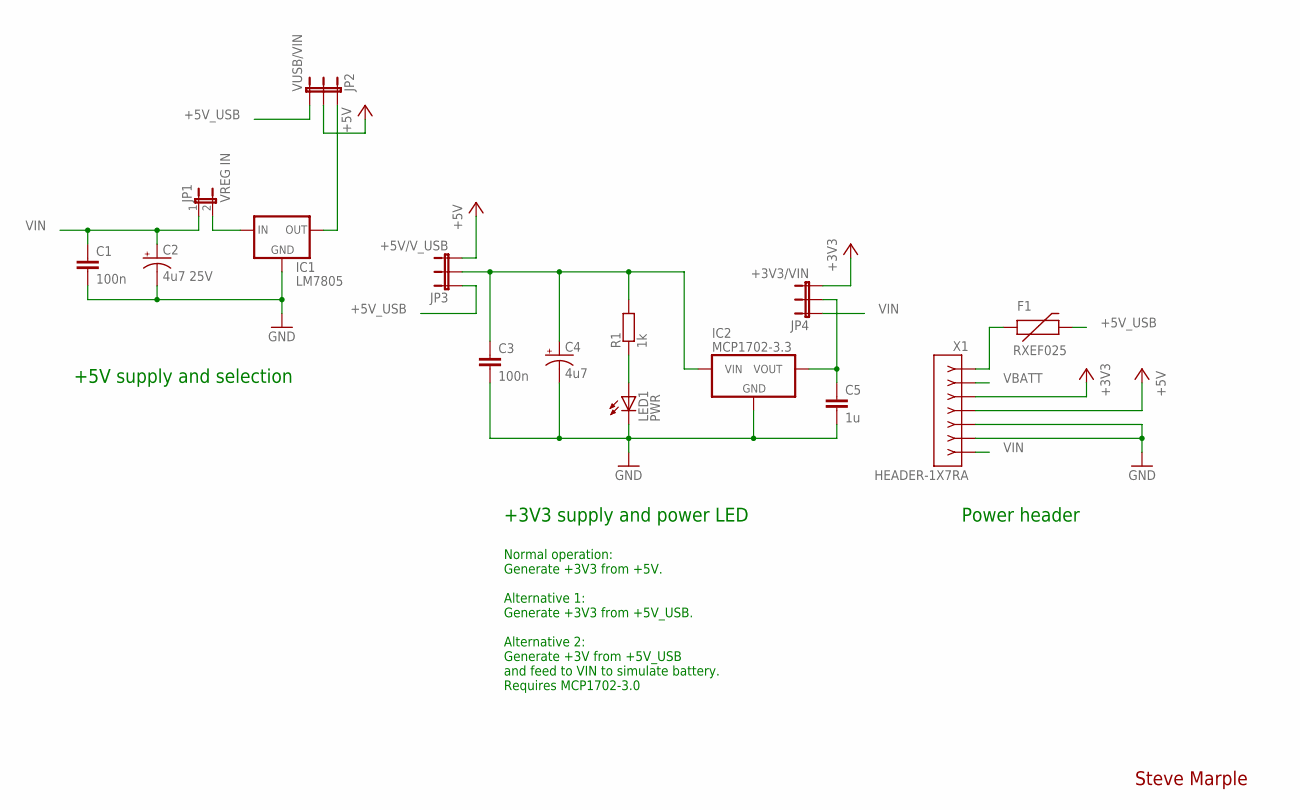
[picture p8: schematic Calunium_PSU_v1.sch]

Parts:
C1, C3: 100n; CAP-PTH-SMALL
C2: 4u7 25V; CPOL-RADIAL-10UF-25V
C4: 4u7; CPOL-RADIAL-10UF-25V
C5: 1u; CAP-PTH-5MM
F1: RXEF025; PTC
IC1: LM7805; 78XXL-NO-HOLE
IC2: MCP1702-3.3; TO-92
JP1: VREG IN; 1X02
JP2: VUSB/VIN; 1X03
JP3: +5V/V_USB; SJ_3
JP4: +3V3/VIN; SJ_3
LED1: PWR; LED3MM
R1: 1k; RES-AXIAL-0.4
X1: HEADER-1X7RA; HEADER-1X7-RA

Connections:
+3V3: JP4.3, X1.3
+5V: JP2.2, JP3.3, X1.4
+5V_USB: F1.P$2 (2), JP2.3, JP3.1
GND: C1.2, C2.2 (-), C3.2, C4.2 (-), C5.2, IC1.GND, IC2.1 (GND), LED1.K (C), X1.5, X1.6
unnamed: F1.P$1 (1), X1.1
unnamed: IC1.IN, JP1.2
unnamed: IC1.OUT, JP2.1
unnamed: C3.1, C4.1 (+), IC2.2 (VIN), JP3.2, R1.P$2 (2)
unnamed: C5.1, IC2.3 (VOUT), JP4.2
unnamed: LED1.A, R1.P$1 (1)
VBATT: X1.2
VIN: C1.1, C2.1 (+), JP1.1, JP4.1, X1.7

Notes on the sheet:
Power header
+5V supply and selection
Steve Marple
+3V3 supply and power LED
Normal operation: Generate +3V3 from +5V. Alternative 1: Generate +3V3 from +5V_USB. Alternative 2: Generate +3V from +5V_USB and feed to VIN to simulate battery. Requires MCP1702-3.0

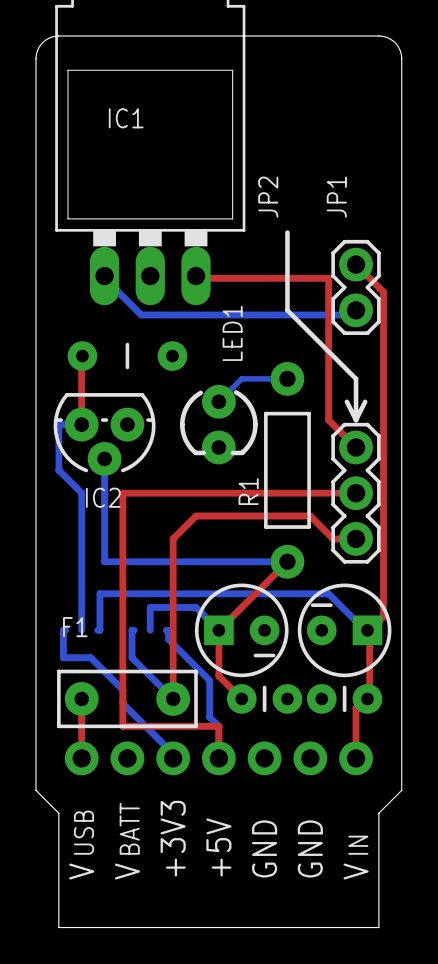
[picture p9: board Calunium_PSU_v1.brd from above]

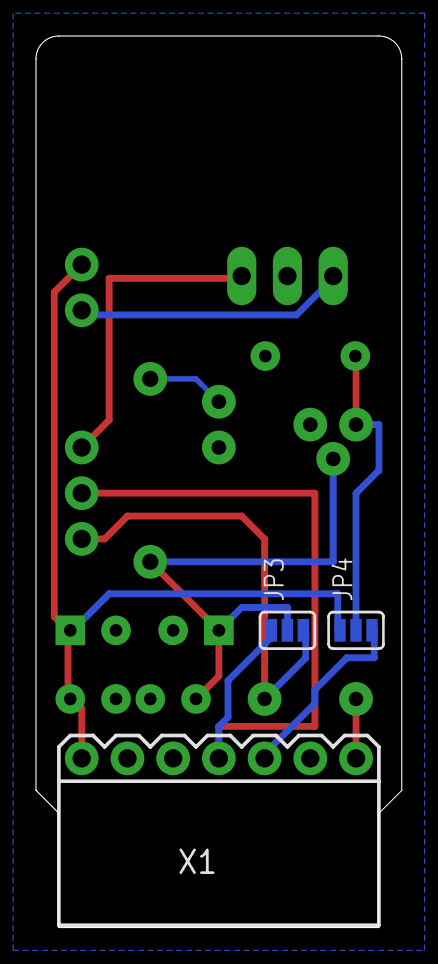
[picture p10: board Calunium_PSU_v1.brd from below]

Board: 2 copper layers, 20.3 x 49.5 mm, 15 parts (3 on the bottom side), 11 nets.

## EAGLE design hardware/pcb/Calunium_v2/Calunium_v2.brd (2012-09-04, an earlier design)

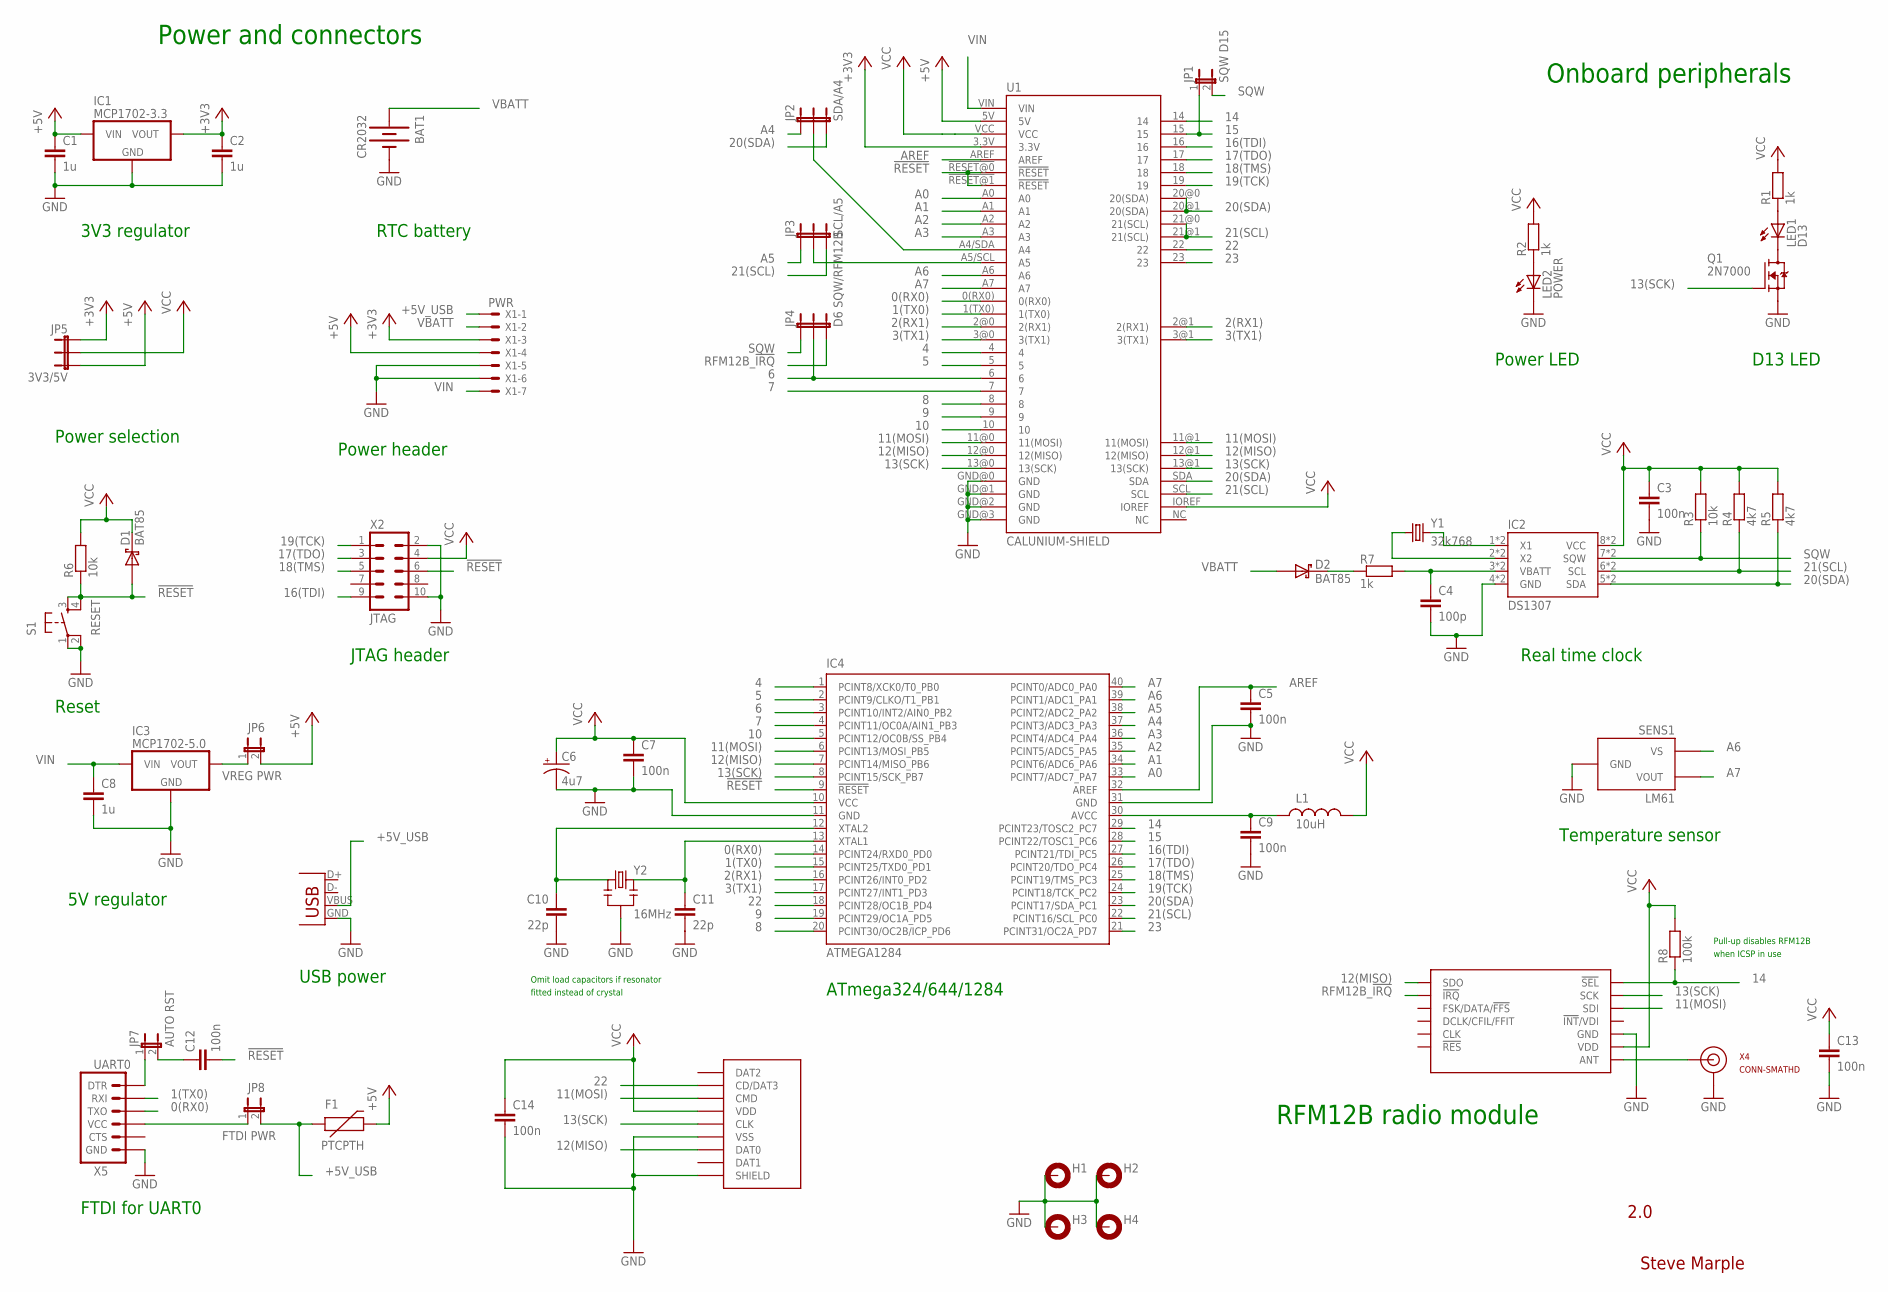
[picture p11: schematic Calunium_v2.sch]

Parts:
BAT1: CR2032; BATTCOM_20MM_PTH
C1, C2, C8: 1u; CAP-PTH-5MM
C3, C5, C7, C9, C12, C13, C14: 100n; CAP-PTH-SMALL
C4: 100p; CAP-PTH-SMALL
C6: 4u7; CPOL-RADIAL-10UF-25V
C10, C11: 22p; CAP-PTH-SMALL
D1, D2: BAT85; DIODE-TH-0.4
F1: PTCPTH; PTC
H1, H2, H3, H4: MOUNT-PAD-ROUND3.0; 3,0-PAD
IC1: MCP1702-3.3; TO-92
IC2: DS1307; DIL08-SOIC8
IC3: MCP1702-5.0; TO-92
IC4: ATMEGA1284; DIL40
JP1: SQW D15; 1X02
JP2: SDA/A4; 1X03
JP3: SCL/A5; 1X03
JP4: D6 SQW/RFM12B; 1X03
JP5: 3V3/5V; 1X03
JP6: VREG PWR; 1X02
JP7: AUTO RST; 1X02
JP8: FTDI PWR; 1X02
L1: 10uH; RES-AXIAL-0.4
LED1: D13; LED3MM
LED2: POWER; LED3MM
Q1: 2N7000; TO-92
R1, R2, R7: 1k; RES-AXIAL-0.4
R3, R6: 10k; RES-AXIAL-0.4
R4, R5: 4k7; RES-AXIAL-0.4
R8: 100k; RES-AXIAL-0.4
RF1: RFM12B
S1: RESET; TACTILE-PTH
SENS1: LM61; TO-92
U1: CALUNIUM-SHIELD; CALUNIUM-SHIELD-NO-OUTLINE-NO-HOLES-NO-TEXT-V2
U$1: MICRO-SD-SOCKETHIROSE-DM3D; MICRO-SD-SOCKET-HIROSE-DM3D
X1: PWR; 22-23-2071
X2: JTAG; CON-HARTING-ML10
X3: USB; USB-B-PTH
X4: CONN-SMATHD; SMA-THD
X5: UART0; MOLEX-1X6-RA_LOCK
Y1: 32k768; TC38H
Y2: 16MHz; HC49U-V-RESONATOR

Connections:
0(RX0): IC4.14 (PCINT24/RXD0_PD0), U1.0(RX0), X5.4 (TXO)
1(TX0): IC4.15 (PCINT25/TXD0_PD1), U1.1(TX0), X5.5 (RXI)
2(RX1): IC4.16 (PCINT26/INT0_PD2), U1.2@0 (2(RX1)), U1.2@1 (2(RX1))
3(TX1): IC4.17 (PCINT27/INT1_PD3), U1.3@0 (3(TX1)), U1.3@1 (3(TX1))
4: IC4.1 (PCINT8/XCK0/T0_PB0), U1.4
5: IC4.2 (PCINT9/CLKO/T1_PB1), U1.5
6: IC4.3 (PCINT10/INT2/AIN0_PB2), JP4.2, U1.6
7: IC4.4 (PCINT11/OC0A/AIN1_PB3), U1.7
8: IC4.20 (PCINT30/OC2B/ICP_PD6), U1.8
9: IC4.19 (PCINT29/OC1A_PD5), U1.9
10: IC4.5 (PCINT12/OC0B/SS_PB4), U1.10
11(MOSI): IC4.6 (PCINT13/MOSI_PB5), RF1.SDI, U1.11@0 (11(MOSI)), U1.11@1 (11(MOSI)), U$1.CMD
12(MISO): IC4.7 (PCINT14/MISO_PB6), RF1.SDO, U1.12@0 (12(MISO)), U1.12@1 (12(MISO)), U$1.DAT0
13(SCK): IC4.8 (PCINT15/SCK_PB7), Q1.2 (G), RF1.SCK, U1.13@0 (13(SCK)), U1.13@1 (13(SCK)), U$1.CLK
14: IC4.29 (PCINT23/TOSC2_PC7), R8.P$1 (1), RF1.!SEL, U1.14
15: IC4.28 (PCINT22/TOSC1_PC6), JP1.1, U1.15
16(TDI): IC4.27 (PCINT21/TDI_PC5), U1.16, X2.9 (TDI)
17(TDO): IC4.26 (PCINT20/TDO_PC4), U1.17, X2.3 (TDO)
18(TMS): IC4.25 (PCINT19/TMS_PC3), U1.18, X2.5 (TMS)
19(TCK): IC4.24 (PCINT18/TCK_PC2), U1.19, X2.1 (TCK)
20(SDA): IC2.5 (SDA), IC2.5@1 (SDA), IC4.23 (PCINT17/SDA_PC1), JP2.3, R5.P$1 (1), U1.20@0 (20(SDA)), U1.20@1 (20(SDA)), U1.SDA
21(SCL): IC2.6 (SCL), IC2.6@1 (SCL), IC4.22 (PCINT16/SCL_PC0), JP3.3, R4.P$1 (1), U1.21@0 (21(SCL)), U1.21@1 (21(SCL)), U1.SCL
22: IC4.18 (PCINT28/OC1B_PD4), U1.22, U$1.CD/DAT3
23: IC4.21 (PCINT31/OC2A_PD7), U1.23
!RESET: C12.2, D1.A, IC4.9 (!RESET), R6.P$1 (1), S1.3, S1.4, U1.!RESET@0 (!RESET), U1.!RESET@1 (!RESET), X2.6 (!SRST)
+3V3: C2.1, IC1.3 (VOUT), JP5.1, U1.3.3V, X1.3
+5V: C1.1, F1.P$2 (2), IC1.2 (VIN), JP5.3, JP6.2, U1.5V, X1.4
+5V_USB: F1.P$1 (1), JP8.2, X1.1, X3.VBUS
A0: IC4.33 (PCINT7/ADC7_PA7), U1.A0
A1: IC4.34 (PCINT6/ADC6_PA6), U1.A1
A2: IC4.35 (PCINT5/ADC5_PA5), U1.A2
A3: IC4.36 (PCINT4/ADC4_PA4), U1.A3
A4: IC4.37 (PCINT3/ADC3_PA3), JP2.1
A5: IC4.38 (PCINT2/ADC2_PA2), JP3.1
A6: IC4.39 (PCINT1/ADC1_PA1), SENS1.1 (VS), U1.A6
A7: IC4.40 (PCINT0/ADC0_PA0), SENS1.2 (VOUT), U1.A7
AREF: C5.1, IC4.32 (AREF), U1.AREF
AVCC: C9.1, IC4.30 (AVCC), L1.P$1 (1)
GND: BAT1.2 (-), C1.2, C2.2, C3.2, C4.2, C5.2, C6.2 (-), C7.2, C8.2, C9.2, C10.2, C11.2, C13.2, C14.2, H1.B3,0, H2.B3,0, H3.B3,0, H4.B3,0, IC1.1 (GND), IC2.4 (GND), IC2.4@1 (GND), IC3.1 (GND), IC4.11 (GND), IC4.31 (GND), LED2.K (C), Q1.1 (S), RF1.GND@0 (GND), RF1.GND@1 (GND), S1.1, S1.2, SENS1.3 (GND), U1.GND@0 (GND), U1.GND@1 (GND), U1.GND@2 (GND), U1.GND@3 (GND), U$1.GND (VSS), U$1.SHIELD@0 (SHIELD), X1.5, X1.6, X2.2 (GND), X2.10 (GND), X3.GND, X4.GND@0 (GND), X4.GND@1 (GND), X4.GND@2 (GND), X4.GND@3 (GND), X5.1 (GND), Y2.GND (2)
unnamed: C11.1, IC4.13 (XTAL1), Y2.2 (3)
unnamed: C10.1, IC4.12 (XTAL2), Y2.1
unnamed: LED1.A, R1.P$1 (1)
unnamed: LED1.K (C), Q1.3 (D)
unnamed: IC2.1 (X1), IC2.1@1 (X1), Y1.2
unnamed: JP2.2, U1.A4/SDA (A4)
unnamed: LED2.A, R2.P$1 (1)
unnamed: D2.C, R7.P$1 (1)
unnamed: JP8.1, X5.3 (VCC)
unnamed: C4.1, IC2.3 (VBATT), IC2.3@1 (VBATT), R7.P$2 (2)
unnamed: IC2.2 (X2), IC2.2@1 (X2), Y1.1
unnamed: JP3.2, U1.A5/SCL (A5)
unnamed: IC3.3 (VOUT), JP6.1
unnamed: JP7.1, X5.6 (DTR)
unnamed: C12.1, JP7.2
unnamed: RF1.ANT, X4.SIG (SIGNAL)
RFM12B_!IRQ: JP4.3, RF1.!IRQ
SQW: IC2.7 (SQW), IC2.7@1 (SQW), JP1.2, JP4.1, R3.P$1 (1)
VBATT: BAT1.1 (+), D2.A, X1.2
VCC: C3.1, C6.1 (+), C7.1, C13.1, C14.1, D1.C, IC2.8 (VCC), IC2.8@1 (VCC), IC4.10 (VCC), JP5.2, L1.P$2 (2), R1.P$2 (2), R2.P$2 (2), R3.P$2 (2), R4.P$2 (2), R5.P$2 (2), R6.P$2 (2), R8.P$2 (2), RF1.VDD, U1.IOREF, U1.VCC, U$1.VDD, X2.4 (VTREF)
VIN: C8.1, IC3.2 (VIN), U1.VIN, X1.7

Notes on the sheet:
Power and connectors
Onboard peripherals
Real time clock
Temperature sensor
ATmega324/644/1284
USB power
FTDI for UART0
JTAG header
D13 LED
Reset
Power selection
Power header
3V3 regulator
RTC battery
Power LED
Steve Marple
2.0
RFM12B radio module
5V regulator
Pull-up disables RFM12B
when ICSP in use
Omit load capacitors if resonator
fitted instead of crystal

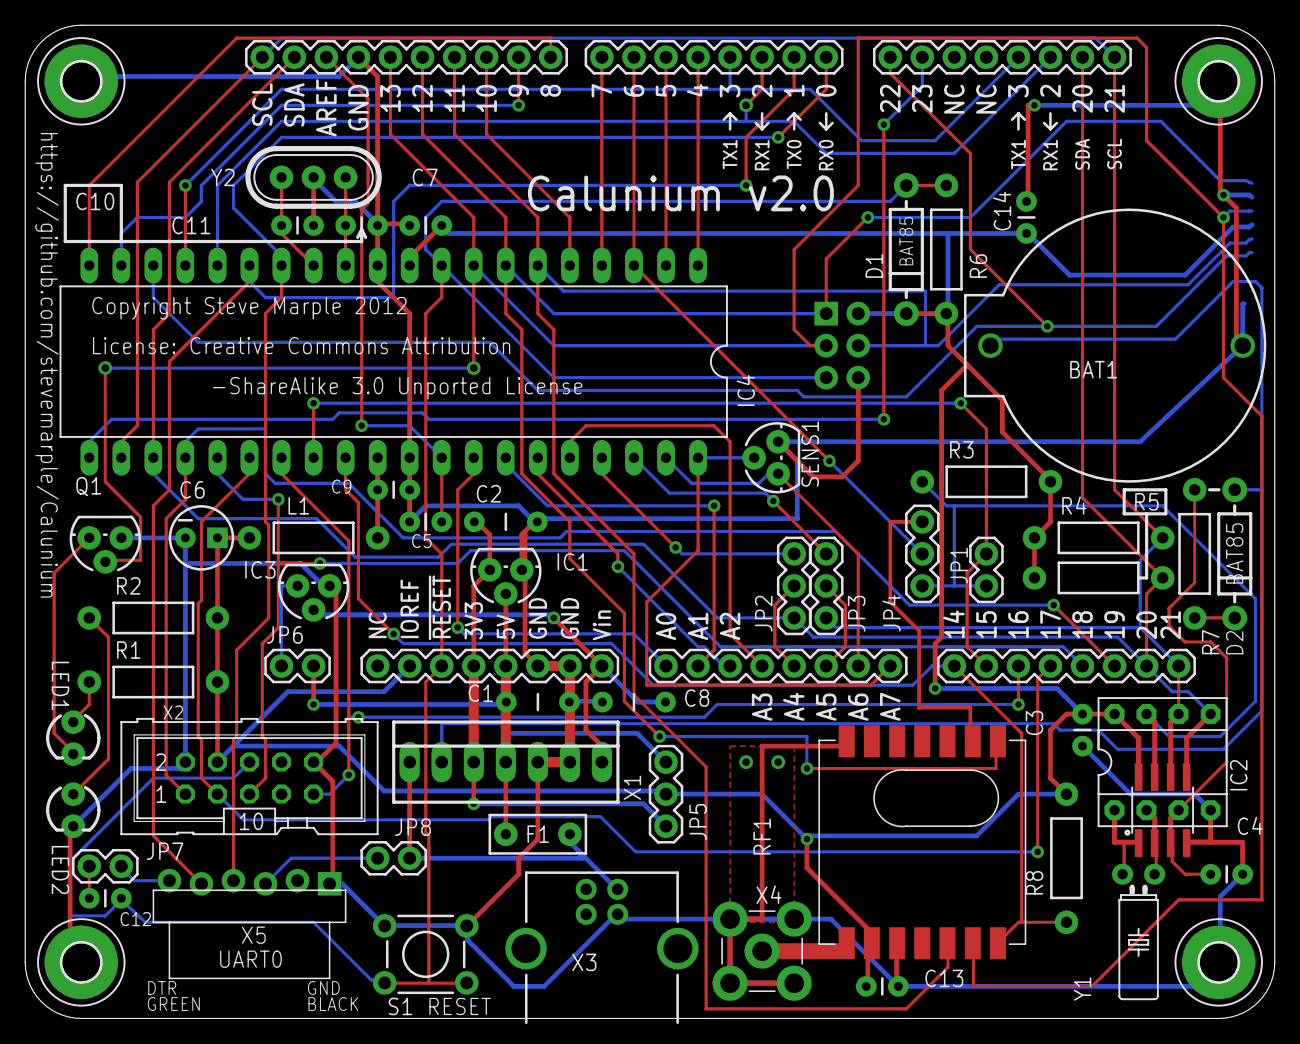
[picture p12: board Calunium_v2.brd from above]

Board: 2 copper layers, 99.1 x 78.7 mm, 58 parts (1 on the bottom side), 60 nets.

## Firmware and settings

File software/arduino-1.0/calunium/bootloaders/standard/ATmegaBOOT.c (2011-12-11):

/**********************************************************/
/* Serial Bootloader for Atmel megaAVR Controllers        */
/*                                                        */
/* tested with ATmega8, ATmega128 and ATmega168           */
/* should work with other mega's, see code for details    */
/*                                                        */
/* ATmegaBOOT.c                                           */
/*                                                        */
/*                                                        */
/* 20090308: integrated Mega changes into main bootloader */
/*           source by D. Mellis                          */
/* 20080930: hacked for Arduino Mega (with the 1280       */
/*           processor, backwards compatible)             */
/*           by D. Cuartielles                            */
/* 20070626: hacked for Arduino Diecimila (which auto-    */
/*           resets when a USB connection is made to it)  */
/*           by D. Mellis                                 */
/* 20060802: hacked for Arduino by D. Cuartielles         */
/*           based on a previous hack by D. Mellis        */
/*           and D. Cuartielles                           */
/*                                                        */
/* Monitor and debug functions were added to the original */
/* code by Dr. Erik Lins, chip45.com. (See below)         */
/*                                                        */
/* Thanks to Karl Pitrich for fixing a bootloader pin     */
/* problem and more informative LED blinking!             */
/*                                                        */
/* For the latest version see:                            */
/* http://www.chip45.com/                                 */
/*                                                        */
/* ------------------------------------------------------ */
/*                                                        */
/* based on stk500boot.c                                  */
/* Copyright (c) 2003, Jason P. Kyle                      */
/* All rights reserved.                                   */
/* see avr1.org for original file and information         */
/*                                                        */
/* This program is free software; you can redistribute it */
/* and/or modify it under the terms of the GNU General    */
/* Public License as published by the Free Software       */
/* Foundation; either version 2 of the License, or        */
/* (at your option) any later version.                    */
/*                                                        */
/* This program is distributed in the hope that it will   */
/* be useful, but WITHOUT ANY WARRANTY; without even the  */
/* implied warranty of MERCHANTABILITY or FITNESS FOR A   */
/* PARTICULAR PURPOSE.  See the GNU General Public        */
/* License for more details.                              */
/*                                                        */
/* You should have received a copy of the GNU General     */
/* Public License along with this program; if not, write  */
/* to the Free Software Foundation, Inc.,                 */
/* 59 Temple Place, Suite 330, Boston, MA  02111-1307 USA */
/*                                                        */
/* Licence can be viewed at                               */
/* http://www.fsf.org/licenses/gpl.txt                    */
/*                                                        */
/* Target = Atmel AVR m128,m64,m32,m16,m8,m162,m163,m169, */
/* m8515,m8535. ATmega161 has a very small boot block so  */
/* isn't supported.                                       */
/*                                                        */
/* Tested with m168                                       */
/**********************************************************/

/* $Id$ */


/* some includes */
#include <inttypes.h>
#include <avr/io.h>
#include <avr/pgmspace.h>
#include <avr/interrupt.h>
#include <avr/wdt.h>
#include <util/delay.h>

/* the current avr-libc eeprom functions do not support the ATmega168 */
/* own eeprom write/read functions are used instead */
#if !defined(__AVR_ATmega168__) || !defined(__AVR_ATmega328P__)
#include <avr/eeprom.h>
#endif

/* Use the F_CPU defined in Makefile */

/* 20060803: hacked by DojoCorp */
/* 20070626: hacked by David A. Mellis to decrease waiting time for auto-reset */
/* set the waiting time for the bootloader */
/* get this from the Makefile instead */
/* #define MAX_TIME_COUNT (F_CPU>>4) */

/* 20070707: hacked by David A. Mellis - after this many errors give up and launch application */
#define MAX_ERROR_COUNT 5
#define NUM_LED_FLASHES 1
/* set the UART baud rate */
/* 20060803: hacked by DojoCorp */
//#define BAUD_RATE   115200
#ifndef BAUD_RATE
#define BAUD_RATE   19200
#endif


/* SW_MAJOR and MINOR needs to be updated from time to time to avoid warning message from AVR Studio */
/* never allow AVR Studio to do an update !!!! */
#define HW_VER	 0x02
#define SW_MAJOR 0x01
#define SW_MINOR 0x10


/* Adjust to suit whatever pin your hardware uses to enter the bootloader */
/* ATmega128 has two UARTS so two pins are used to enter bootloader and select UART */
/* ATmega1280 has four UARTS, but for Arduino Mega, we will only use RXD0 to get code */
/* BL0... means UART0, BL1... means UART1 */
#ifdef __AVR_ATmega128__
#define BL_DDR  DDRF
#define BL_PORT PORTF
#define BL_PIN  PINF
#define BL0     PINF7
#define BL1     PINF6
#elif defined __AVR_ATmega1280__ 
/* we just don't do anything for the MEGA and enter bootloader on reset anyway*/
#elif defined(__AVR_ATmega164P__) || defined(__AVR_ATmega324P__) || defined(__AVR_ATmega644__) || defined(__AVR_ATmega644P__) || defined(__AVR_ATmega1284P__)

#else
/* other ATmegas have only one UART, so only one pin is defined to enter bootloader */
#define BL_DDR  DDRD
#define BL_PORT PORTD
#define BL_PIN  PIND
#define BL      PIND6
#endif


/* onboard LED is used to indicate, that the bootloader was entered (3x flashing) */
/* if monitor functions are included, LED goes on after monitor was entered */
#ifdef LED_DDR
/* Assume LED_PORT, LED_PIN and LED are already defined */
#elif defined __AVR_ATmega128__ || defined __AVR_ATmega1280__
/* Onboard LED is connected to pin PB7 (e.g. Crumb128, PROBOmega128, Savvy128, Arduino Mega) */
#define LED_DDR  DDRB
#define LED_PORT PORTB
#define LED_PIN  PINB
#define LED      PINB7
#elif defined __AVR_ATmega1284P__
#define LED_DDR  DDRB
#define LED_PORT PORTB
#define LED_PIN  PINB
#define LED      PINB0
#else
/* Onboard LED is connected to pin PB5 in Arduino NG, Diecimila, and Duomilanuove */ 
/* other boards like e.g. Crumb8, Crumb168 are using PB2 */
#define LED_DDR  DDRB
#define LED_PORT PORTB
#define LED_PIN  PINB
#define LED      PINB5
#endif


/* monitor functions will only be compiled when using ATmega128, due to bootblock size constraints */
#if defined(__AVR_ATmega128__) || defined(__AVR_ATmega1280__)
#define MONITOR 1
#endif


/* define various device id's */
/* manufacturer byte is always the same */
#define SIG1	0x1E	// Yep, Atmel is the only manufacturer of AVR micros.  Single source :(

#if defined __AVR_ATmega1280__
#define SIG2	0x97
#define SIG3	0x03
#define PAGE_SIZE	0x80U	//128 words

#elif defined __AVR_ATmega164P__
#define SIG2	0x94
#define SIG3	0x0F
#define PAGE_SIZE	0x080U   //128 words

#elif defined __AVR_ATmega324P__
#define SIG2	0x95
#define SIG3	0x11
#define PAGE_SIZE	0x080U   //128 words

#elif defined __AVR_ATmega644__
#define SIG2	0x96
#define SIG3	0x09
#define PAGE_SIZE	0x080U   //128 words

#elif defined __AVR_ATmega644P__
#define SIG2	0x96
#define SIG3	0x0A
#define PAGE_SIZE	0x080U   //128 words

#elif defined __AVR_ATmega1284P__
#define SIG2	0x97
#define SIG3	0x05
#define PAGE_SIZE	0x080U   //128 words

#elif defined __AVR_ATmega1281__
#define SIG2	0x97
#define SIG3	0x04
#define PAGE_SIZE	0x80U	//128 words

#elif defined __AVR_ATmega128__
#define SIG2	0x97
#define SIG3	0x02
#define PAGE_SIZE	0x80U	//128 words

#elif defined __AVR_ATmega64__
#define SIG2	0x96
#define SIG3	0x02
#define PAGE_SIZE	0x80U	//128 words

#elif defined __AVR_ATmega32__
#define SIG2	0x95
#define SIG3	0x02
#define PAGE_SIZE	0x40U	//64 words

#elif defined __AVR_ATmega16__
#define SIG2	0x94
#define SIG3	0x03
#define PAGE_SIZE	0x40U	//64 words

#elif defined __AVR_ATmega8__
#define SIG2	0x93
#define SIG3	0x07
#define PAGE_SIZE	0x20U	//32 words

#elif defined __AVR_ATmega88__
#define SIG2	0x93
#define SIG3	0x0a
#define PAGE_SIZE	0x20U	//32 words

#elif defined __AVR_ATmega168__
#define SIG2	0x94
#define SIG3	0x06
#define PAGE_SIZE	0x40U	//64 words

#elif defined __AVR_ATmega328P__
#define SIG2	0x95
#define SIG3	0x0F
#define PAGE_SIZE	0x40U	//64 words

#elif defined __AVR_ATmega162__
#define SIG2	0x94
#define SIG3	0x04
#define PAGE_SIZE	0x40U	//64 words

#elif defined __AVR_ATmega163__
#define SIG2	0x94
#define SIG3	0x02
#define PAGE_SIZE	0x40U	//64 words

#elif defined __AVR_ATmega169__
#define SIG2	0x94
#define SIG3	0x05
#define PAGE_SIZE	0x40U	//64 words

#elif defined __AVR_ATmega8515__
#define SIG2	0x93
#define SIG3	0x06
#define PAGE_SIZE	0x20U	//32 words

#elif defined __AVR_ATmega8535__
#define SIG2	0x93
#define SIG3	0x08
#define PAGE_SIZE	0x20U	//32 words
#endif


/* function prototypes */
void putch(char);
char getch(void);
void getNch(uint8_t);
void byte_response(uint8_t);
void nothing_response(void);
char gethex(void);
void puthex(char);
void flash_led(uint8_t);

/* some variables */
union address_union {
	uint16_t word;
	uint8_t  byte[2];
} address;

union length_union {
	uint16_t word;
	uint8_t  byte[2];
} length;

struct flags_struct {
	unsigned eeprom : 1;
	unsigned rampz  : 1;
} flags;

uint8_t buff[256];
uint8_t address_high;

uint8_t pagesz=0x80;

uint8_t i;
uint8_t bootuart = 0;

uint8_t error_count = 0;

void (*app_start)(void) = 0x0000;


/* main program starts here */
int main(void)
{
	uint8_t ch,ch2;
	uint16_t w;

#ifdef WATCHDOG_MODS
	ch = MCUSR;
	MCUSR = 0;

	WDTCSR |= _BV(WDCE) | _BV(WDE);
	WDTCSR = 0;

	// Check if the WDT was used to reset, in which case we dont bootload and skip straight to the code. woot.
	if (! (ch &  _BV(EXTRF))) // if its a not an external reset...
		app_start();  // skip bootloader
#else
	asm volatile("nop\n\t");
#endif

	/* set pin direction for bootloader pin and enable pullup */
	/* for ATmega128, two pins need to be initialized */
#ifdef __AVR_ATmega128__
	BL_DDR &= ~_BV(BL0);
	BL_DDR &= ~_BV(BL1);
	BL_PORT |= _BV(BL0);
	BL_PORT |= _BV(BL1);
#else
	/* We run the bootloader regardless of the state of this pin.  Thus, don't
	put it in a different state than the other pins.  --DAM, 070709
	This also applies to Arduino Mega -- DC, 080930
	BL_DDR &= ~_BV(BL);
	BL_PORT |= _BV(BL);
	*/
#endif


#ifdef __AVR_ATmega128__
	/* check which UART should be used for booting */
	if(bit_is_clear(BL_PIN, BL0)) {
		bootuart = 1;
	}
	else if(bit_is_clear(BL_PIN, BL1)) {
		bootuart = 2;
	}
#endif

#if defined __AVR_ATmega1280__  || defined(__AVR_ATmega164P__) || defined(__AVR_ATmega324P__) || defined(__AVR_ATmega644__) || defined(__AVR_ATmega644P__) || defined(__AVR_ATmega1284P__)
	/* the mega1280 chip has four serial ports ... we could eventually use any of them, or not? */
	/* however, we don't wanna confuse people, to avoid making a mess, we will stick to RXD0, TXD0 */
	bootuart = 1;
#endif

	/* check if flash is programmed already, if not start bootloader anyway */
	if(pgm_read_byte_near(0x0000) != 0xFF) {

#ifdef __AVR_ATmega128__
	/* no UART was selected, start application */
	if(!bootuart) {
		app_start();
	}
#else
	/* check if bootloader pin is set low */
	/* we don't start this part neither for the m8, nor m168 */
	//if(bit_is_set(BL_PIN, BL)) {
	//      app_start();
	//    }
#endif
	}

#ifdef __AVR_ATmega128__    
	/* no bootuart was selected, default to uart 0 */
	if(!bootuart) {
		bootuart = 1;
	}
#endif


	/* initialize UART(s) depending on CPU defined */
#if defined(__AVR_ATmega128__) || defined(__AVR_ATmega1280__)  || defined(__AVR_ATmega164P__) || defined(__AVR_ATmega324P__) || defined(__AVR_ATmega644__) || defined(__AVR_ATmega644P__) || defined(__AVR_ATmega1284P__)
	if(bootuart == 1) {
		UBRR0L = (uint8_t)(F_CPU/(BAUD_RATE*16L)-1);
		UBRR0H = (F_CPU/(BAUD_RATE*16L)-1) >> 8;
		UCSR0A = 0x00;
		UCSR0C = 0x06;
		UCSR0B = _BV(TXEN0)|_BV(RXEN0);
	}
	if(bootuart == 2) {
		UBRR1L = (uint8_t)(F_CPU/(BAUD_RATE*16L)-1);
		UBRR1H = (F_CPU/(BAUD_RATE*16L)-1) >> 8;
		UCSR1A = 0x00;
		UCSR1C = 0x06;
		UCSR1B = _BV(TXEN1)|_BV(RXEN1);
	}
#elif defined __AVR_ATmega163__
	UBRR = (uint8_t)(F_CPU/(BAUD_RATE*16L)-1);
	UBRRHI = (F_CPU/(BAUD_RATE*16L)-1) >> 8;
	UCSRA = 0x00;
	UCSRB = _BV(TXEN)|_BV(RXEN);	
#elif defined(__AVR_ATmega168__) || defined(__AVR_ATmega328P__)

#ifdef DOUBLE_SPEED
	UCSR0A = (1<<U2X0); //Double speed mode USART0
	UBRR0L = (uint8_t)(F_CPU/(BAUD_RATE*8L)-1);
	UBRR0H = (F_CPU/(BAUD_RATE*8L)-1) >> 8;
#else
	UBRR0L = (uint8_t)(F_CPU/(BAUD_RATE*16L)-1);
	UBRR0H = (F_CPU/(BAUD_RATE*16L)-1) >> 8;
#endif

	UCSR0B = (1<<RXEN0) | (1<<TXEN0);
	UCSR0C = (1<<UCSZ00) | (1<<UCSZ01);

	/* Enable internal pull-up resistor on pin D0 (RX), in order
	to supress line noise that prevents the bootloader from
	timing out (DAM: 20070509) */
	DDRD &= ~_BV(PIND0);
	PORTD |= _BV(PIND0);
#elif defined __AVR_ATmega8__
	/* m8 */
	UBRRH = (((F_CPU/BAUD_RATE)/16)-1)>>8; 	// set baud rate
	UBRRL = (((F_CPU/BAUD_RATE)/16)-1);
	UCSRB = (1<<RXEN)|(1<<TXEN);  // enable Rx & Tx
	UCSRC = (1<<URSEL)|(1<<UCSZ1)|(1<<UCSZ0);  // config USART; 8N1
#else
	/* m16,m32,m169,m8515,m8535 */
	UBRRL = (uint8_t)(F_CPU/(BAUD_RATE*16L)-1);
	UBRRH = (F_CPU/(BAUD_RATE*16L)-1) >> 8;
	UCSRA = 0x00;
	UCSRC = 0x06;
	UCSRB = _BV(TXEN)|_BV(RXEN);
#endif

#if defined __AVR_ATmega1280__
	/* Enable internal pull-up resistor on pin D0 (RX), in order
	to supress line noise that prevents the bootloader from
	timing out (DAM: 20070509) */
	/* feature added to the Arduino Mega --DC: 080930 */
	DDRE &= ~_BV(PINE0);
	PORTE |= _BV(PINE0);
#endif


	/* set LED pin as output */
	LED_DDR |= _BV(LED);


	/* flash onboard LED to signal entering of bootloader */
#if defined(__AVR_ATmega128__) || defined(__AVR_ATmega1280__) || defined(__AVR_ATmega164P__) || defined(__AVR_ATmega324P__) || defined(__AVR_ATmega644__) || defined(__AVR_ATmega644P__) || defined(__AVR_ATmega1284P__)
	// 4x for UART0, 5x for UART1
	flash_led(NUM_LED_FLASHES + bootuart);
#else
	flash_led(NUM_LED_FLASHES);
#endif

	/* 20050803: by DojoCorp, this is one of the parts provoking the
		 system to stop listening, cancelled from the original */
	//putch('\0');

	/* forever loop */
	for (;;) {

	/* get character from UART */
	ch = getch();

	/* A bunch of if...else if... gives smaller code than switch...case ! */

	/* Hello is anyone home ? */ 
	if(ch=='0') {
		nothing_response();
	}


	/* Request programmer ID */
	/* Not using PROGMEM string due to boot block in m128 being beyond 64kB boundry  */
	/* Would need to selectively manipulate RAMPZ, and it's only 9 characters anyway so who cares.  */
	else if(ch=='1') {
		if (getch() == ' ') {
			putch(0x14);
			putch('A');
			putch('V');
			putch('R');
			putch(' ');
			putch('I');
			putch('S');
			putch('P');
			putch(0x10);
		} else {
			if (++error_count == MAX_ERROR_COUNT)
				app_start();
		}
	}


	/* AVR ISP/STK500 board commands  DON'T CARE so default nothing_response */
	else if(ch=='@') {
		ch2 = getch();
		if (ch2>0x85) getch();
		nothing_response();
	}


	/* AVR ISP/STK500 board requests */
	else if(ch=='A') {
		ch2 = getch();
		if(ch2==0x80) byte_response(HW_VER);		// Hardware version
		else if(ch2==0x81) byte_response(SW_MAJOR);	// Software major version
		else if(ch2==0x82) byte_response(SW_MINOR);	// Software minor version
		else if(ch2==0x98) byte_response(0x03);		// Unknown but seems to be required by avr studio 3.56
		else byte_response(0x00);				// Covers various unnecessary responses we don't care about
	}


	/* Device Parameters  DON'T CARE, DEVICE IS FIXED  */
	else if(ch=='B') {
		getNch(20);
		nothing_response();
	}


	/* Parallel programming stuff  DON'T CARE  */
	else if(ch=='E') {
		getNch(5);
		nothing_response();
	}


	/* P: Enter programming mode  */
	/* R: Erase device, don't care as we will erase one page at a time anyway.  */
	else if(ch=='P' || ch=='R') {
		nothing_response();
	}


	/* Leave programming mode  */
	else if(ch=='Q') {
		nothing_response();
#ifdef WATCHDOG_MODS
		// autoreset via watchdog (sneaky!)
		WDTCSR = _BV(WDE);
		while (1); // 16 ms
#endif
	}


	/* Set address, little endian. EEPROM in bytes, FLASH in words  */
	/* Perhaps extra address bytes may be added in future to support > 128kB FLASH.  */
	/* This might explain why little endian was used here, big endian used everywhere else.  */
	else if(ch=='U') {
		address.byte[0] = getch();
		address.byte[1] = getch();
		nothing_response();
	}


	/* Universal SPI programming command, disabled.  Would be used for fuses and lock bits.  */
	else if(ch=='V') {
		if (getch() == 0x30) {
			getch();
			ch = getch();
			getch();
			if (ch == 0) {
				byte_response(SIG1);
			} else if (ch == 1) {
				byte_response(SIG2); 
			} else {
				byte_response(SIG3);
			} 
		} else {
			getNch(3);
			byte_response(0x00);
		}
	}


	/* Write memory, length is big endian and is in bytes  */
	else if(ch=='d') {
		length.byte[1] = getch();
		length.byte[0] = getch();
		flags.eeprom = 0;
		if (getch() == 'E') flags.eeprom = 1;
		for (w=0;w<length.word;w++) {
			buff[w] = getch();	                        // Store data in buffer, can't keep up with serial data stream whilst programming pages
		}
		if (getch() == ' ') {
			if (flags.eeprom) {		                //Write to EEPROM one byte at a time
				address.word <<= 1;
				for(w=0;w<length.word;w++) {
#if defined(__AVR_ATmega168__)  || defined(__AVR_ATmega328P__)
					while(EECR & (1<<EEPE));
					EEAR = (uint16_t)(void *)address.word;
					EEDR = buff[w];
					EECR |= (1<<EEMPE);
					EECR |= (1<<EEPE);
#else
					eeprom_write_byte((void *)address.word,buff[w]);
#endif
					address.word++;
				}			
			}
			else {					        //Write to FLASH one page at a time
				if (address.byte[1]>127) address_high = 0x01;	//Only possible with m128, m256 will need 3rd address byte. FIXME
				else address_high = 0x00;
#if defined(__AVR_ATmega128__) || defined(__AVR_ATmega1280__) || defined(__AVR_ATmega1281__) || defined(__AVR_ATmega1284P__)
				RAMPZ = address_high;
#endif
				address.word = address.word << 1;	        //address * 2 -> byte location
				/* if ((length.byte[0] & 0x01) == 0x01) length.word++;	//Even up an odd number of bytes */
				if ((length.byte[0] & 0x01)) length.word++;	//Even up an odd number of bytes
				cli();					//Disable interrupts, just to be sure
#if defined(__AVR_ATmega1280__) || defined(__AVR_ATmega1281__) || defined(__AVR_ATmega164P__) || defined(__AVR_ATmega324P__) || defined(__AVR_ATmega644__) || defined(__AVR_ATmega644P__) || defined(__AVR_ATmega1284P__)
				while(bit_is_set(EECR,EEPE));			//Wait for previous EEPROM writes to complete
#else
				while(bit_is_set(EECR,EEWE));			//Wait for previous EEPROM writes to complete
#endif
				asm volatile(
					 "clr	r17		\n\t"	//page_word_count
					 "lds	r30,address	\n\t"	//Address of FLASH location (in bytes)
					 "lds	r31,address+1	\n\t"
					 "ldi	r28,lo8(buff)	\n\t"	//Start of buffer array in RAM
					 "ldi	r29,hi8(buff)	\n\t"
					 "lds	r24,length	\n\t"	//Length of data to be written (in bytes)
					 "lds	r25,length+1	\n\t"
					 "length_loop:		\n\t"	//Main loop, repeat for number of words in block							 							 
					 "cpi	r17,0x00	\n\t"	//If page_word_count=0 then erase page
					 "brne	no_page_erase	\n\t"						 
					 "wait_spm1:		\n\t"
					 "lds	r16,%0		\n\t"	//Wait for previous spm to complete
					 "andi	r16,1           \n\t"
					 "cpi	r16,1           \n\t"
					 "breq	wait_spm1       \n\t"
					 "ldi	r16,0x03	\n\t"	//Erase page pointed to by Z
					 "sts	%0,r16		\n\t"
					 "spm			\n\t"							 
#ifdef __AVR_ATmega163__
					 ".word 0xFFFF		\n\t"
					 "nop			\n\t"
#endif
					 "wait_spm2:		\n\t"
					 "lds	r16,%0		\n\t"	//Wait for previous spm to complete
					 "andi	r16,1           \n\t"
					 "cpi	r16,1           \n\t"
					 "breq	wait_spm2       \n\t"
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

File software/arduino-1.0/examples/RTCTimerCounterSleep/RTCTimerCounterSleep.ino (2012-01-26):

/*
 * RTCTimerCounterSleep.ino
 * Author: Steve Marple
 * License: Gnu General Public License version 2 
 *
 * Example sketch to demonstrate sleep. Waking is controlled by the
 * real-time clock outputting a 4096Hz square wave which is used as an
 * input by timer/counter2 on the ATmega1284P. An interrupt service
 * routine is called when timer/counter2 has reached its TOP (not MAX
 * or overflow) value; the ISR sets isrRan to true. Every run of
 * loop() checks if the isrRan is true; if so it is set to false and
 * the current time is printed to the console. The state of
 * LED_BUILTIN is also toggled, to flash the on-board LED.
 *
 * Precautions must be taken when then asynchronous mode of
 * timer/counter2 is used to enable wakeup, see comment in the code
 * below. Using a 1Hz signal instead of the 4096Hz signal is possible
 * but the time taken to return to sleep in increased.
 *
 * To run this sketch on a standard Arduino (ATmega168 or ATmega328)
 * you will need to use timer/counter1; define USE_CT to be 1. Use D5
 * for the input. Using timer/counter2 might be possible if your
 * ATmega328 uses the internal oscillator and the crystal is not
 * fitted.
 * 
 * This sketch will not work in asynchronous mode with an Arduino
 * Mega(2560) since the TOSC1 pin is not connected to the shield
 * headers; use one of the synchronous counters instead.
 *
 * Requirements:
 *   Arduino >= 1.0
 *   RealTimeClockDS1307, see
 *     https://github.com/davidhbrown/RealTimeClockDS1307
 *
 *   Calunium configuration:
 *     RTC (DS1307 or similar) fitted, with battery
 *     RTC square wave routed to D15 (JP1 fitted)
 */

#include <Wire.h>
#include <RealTimeClockDS1307.h>

#include <avr/sleep.h>

bool ledValue = true;

// Use an 8-bit variable to obtain atomic read/write access. Disabling
// interrupts is therefore not needed as long as only this variable is
// accessed.
volatile bool isrRan = false;

// With a 4096Hz input and divide by 1024 prescaler there are 4 counts
// per second; wakeup every 5 seconds (count = 20)
#define WAKEUP_COUNT 20

// Select which timer/counter to use
#define USE_CT 2

#if USE_CT == 1
ISR(TIMER1_COMPA_vect)
{
  isrRan = true;
}

// Configure counter/timer1. Count the falling edges to have the ticks
// occuring on the second boundary. 
void setupTimer1(void)
{
  noInterrupts();
  ASSR = _BV(AS2);
  TCCR1A = 0;
  TCCR1B = 0;
  TCNT1 = 0;
  OCR1A = (WAKEUP_COUNT - 1);
  TCCR1B |= _BV(WGM12); // CTC mode
  TCCR1B |= (_BV(CS12) | _BV(CS11)); // External clock source, falling edge
  TCCR2B |= (_BV(CS12) | _BV(CS11) | _BV(CS10));  // Divide by 1024
  TIMSK1 |= _BV(OCIE1A);
  interrupts();
}

#elif USE_CT == 2
ISR(TIMER2_COMPA_vect)
{
  isrRan = true;
}

// Configure counter/timer2 in asynchronous mode, counting the rising
// edge of signals on TOSC1. This always triggers on the rising edge;
// if connecting SQW from a DS1307 then this means the ticks occur
// halfway through the second at 1Hz.
void setupTimer2(void)
{
  noInterrupts();
  ASSR = (_BV(EXCLK) | _BV(AS2));
  TCCR2A = 0;
  TCCR2B = 0;
  TCNT2 = 0;
  OCR2A = (WAKEUP_COUNT - 1); // Have the ISR called every 4th (n+1) tick
  TCCR2A |= _BV(WGM21); // CTC mode
  TCCR2B |= (_BV(CS22) | _BV(CS21) | _BV(CS20));  // Divide by 1024
  TIMSK2 |= _BV(OCIE2A);
  interrupts();
}

#else
#error "Not configured for this timer"
#endif

void doSleep(uint8_t mode)
{
  noInterrupts();
  set_sleep_mode(mode); // Set the mode
  sleep_enable();       // Make sleeping possible
  interrupts();         // Make sure wake up is possible!
  sleep_cpu();          // Now go to sleep

  // Now awake again
  sleep_disable();      // Make sure sleep can't happen until we are ready

  /*
   * Fix a suspected bug in the two-wire hardware which stops it
   * working after sleep. See
   * http://www.avrfreaks.net/index.php?name=PNphpBB2&file=viewtopic&t=22549
   */
  TWCR &= ~(_BV(TWSTO) + _BV(TWEN));
  TWCR |= _BV(TWEN); 
}


void setup(void)
{
  pinMode(SS, OUTPUT); // Prevent SPI slave mode from happening
  Wire.begin();
  Serial.begin(9600);

  // For calunium: enable inputs on pin 6 in case JP4 is fitted and
  // routing SQW there also
  pinMode(6, INPUT); 

  // Setup the LED
  pinMode(LED_BUILTIN, OUTPUT);
  digitalWrite(LED_BUILTIN, ledValue);
  
#if USE_CT == 1
  // Use counter/timer1. On Calunium digital pin 5 is T1, adjust for
  // if necessary your board.
  pinMode(5, INPUT); // Make T1 pin an input
  setupTimer1();

#elif USE_CT == 2
  pinMode(15, INPUT);
  setupTimer2();
#else
#error "Not configured for this timer"
#endif

  // Set up the RTC output
  RTC.sqwEnable(RealTimeClockDS1307::SQW_4kHz);
  Serial.println("Done setup()");
  delay(100);
}


unsigned long last = 0;
void loop(void) 
{
  // Print if the interrupt service routine was called, and the
  // current number of seconds in the minute
  if (isrRan) {
    isrRan = false;
    ledValue = !ledValue;
    digitalWrite(LED_BUILTIN, ledValue);
    Serial.print("***** ISR called: ");
    RTC.readClock();
    Serial.println(RTC.getSeconds());
  }

  Serial.print("In loop()"); 

  /*
   * Now sleep, but see caveat from the data sheet:
   *
   * If Timer/Counter2 is used to wake the device up from Power-save
   * or ADC Noise Reduction mode, precautions must be taken if the
   * user wants to re-enter one of these modes: The interrupt logic
   * needs one TOSC1 cycle to be reset. If the time between wake-up
   * and reentering sleep mode is less than one TOSC1 cycle, the
   * interrupt will not occur, and the device will fail to wake up. If
   * the user is in doubt whether the time before re-entering
   * Power-save or ADC Noise Reduction mode is sufficient, the
   * following algorithm can be used to ensure that one TOSC1 cycle
   * has elapsed:
   *
   * - a. Write a value to TCCR2x, TCNT2, or OCR2x.
   * - b. Wait until the corresponding Update Busy Flag in ASSR returns to zero.
   * - c. Enter Power-save or ADC Noise Reduction mode.
   */

#if USE_CT == 2
  OCR2A = (WAKEUP_COUNT - 1);
  while (ASSR & _BV(OCR2AUB))
    ; 
#endif

  doSleep(SLEEP_MODE_PWR_SAVE);
}

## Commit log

2011-08-16 Initial commit.
    [Calunium.fz, Calunium.fzz]
2011-10-10 Moved stripboard deisgns to separate directory.
    [Calunium.fz, Calunium.fzz]
2011-10-10 Added Eagle PCB design files.
    Added Eagle schematic (.sch) and board (.brd) files, the schematic
    exported in PDF and PNG formats, and the Gerber RS-274x format files
    (.{G[TB][LOS],TXT}) used for PCB manufacture.
    [Calunium_v1.brd, Calunium_v1.sch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]
2011-10-10 Updated readme.txt now that strip board and PCB designs exist.
2011-11-19 Adding files to support Calunium in the Arduino IDE.
2011-11-19 Adding pin change details.
2011-12-11 Fixing bootloader names in boards.txt.
2011-12-25 Adding link to information about the PCB version.
2012-01-11 Indicating Arduino 1.0 is required.
2012-01-14 Updating core files from Arduino master respoitory to support interrupts
2012-01-14 Adding examples for using the on-board real time clock
2012-01-15 Adding example to use the RTC with timer/counter input
2012-01-16 Adding example to use the RTC with pin change interrupts.
2012-01-22 Fixing the definition (pcb) of CALUNIUM_VARIANT to match the path.
2012-04-30 Using wiring_analog.c from mighty-1284p to support correct analog mapping.
2012-04-30 Fixing pin mapping to use the features from mighty-1284p.
2012-05-01 Ensuring C linkage for pin mapping header files
2012-06-18 Preliminary Calunium v2 PCB design
    [Calunium_v1.brd, Calunium_v1.sch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]
2012-06-18 Moving v1 schematics.
2012-09-04 Updating v2.0 PCB design files.
    [Calunium_v2.brd, Calunium_v2.sch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]
2012-12-01 Fixing C compatibility. LED pin renamed to LED_BUILTIN.
2012-12-01 Adding extra board options for xboot.
2013-01-09 Adding Calunium v2.1 design files.
    Almost identical to v2.1 but with MCP2200 USB interface added. Untested layout.
    [Calunium_v2.1.brd, Calunium_v2.1.sch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]
2013-01-10 Add load capacitors for MCP7941x RTC. Removed DIP footprint for RTC.
    [Calunium_v2.1.brd, Calunium_v2.1.sch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]
2013-02-10 Use standard arduino core. Reduced baudrate for 8MHz board.
2013-02-19 Adding correction for silkscreen error.
    [Calunium_v2.1a.brd, Calunium_v2.1a.sch]
2014-01-18 Fixing error where MCP2200 autoreset was not routed through JP7.
    [Calunium_v2.1a.brd, Calunium_v2.1a.sch]
2014-01-23 Adding Eagle PCB design for PSU which plugs onto Molex power connector.
    [Calunium_PSU_v1.brd, Calunium_PSU_v1.sch]
2014-01-29 Adding 1M pull-down resistor on D13.
    [Calunium_v2.1a.brd, Calunium_v2.1a.sch]
2014-01-31 Adding juumper to disconnect VCC from ISP header, routing improvements.
    [Calunium_v2.1a.brd, Calunium_v2.1a.sch]
2014-03-05 Ignoring Eagle backup files and unwanted Gerber files.
2014-11-07 Minor routing changes to increase trace separation.
    [Calunium_v2.1a.brd]
2014-11-07 Adding design rules file used for PCB layout.
2014-11-07 Renamed directory to follow pattern used previously for different versions.
    [Calunium_v2.1a.brd, Calunium_v2.1a.sch]
2015-10-07 Refactor to support arduino v1.0 and v1.6
2015-10-07 Update board definitions
2015-10-13 Updated and new xboot bootloaders.
    Compiled with avr-gcc version 4.8.1. New bootloaders for
    ATmega1284 (non-P version). Watchdog timer enabled (8s).
2015-12-13 Fix PCB/stripboard variant menu option

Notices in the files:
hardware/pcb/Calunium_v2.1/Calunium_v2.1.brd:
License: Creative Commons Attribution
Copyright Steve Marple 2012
